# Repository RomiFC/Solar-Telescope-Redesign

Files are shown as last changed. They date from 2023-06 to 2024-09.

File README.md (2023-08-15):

# Solar-Telescope-Redesign

This goal of this project is to redesign and modernize a solar telescope initially created some time before 2013. The telescope receives RF energy from the sun through an x-band feed horn antenna, amplifies and rectifies the signal, then outputs the signal to a voltmeter. More information is available under the [official documentation](/Report/002.35.25.05.20-002-REP-SolarTeleRedesign.pdf).

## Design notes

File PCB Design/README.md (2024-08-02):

# Changelog

## Revision B - 7/24/2024

### Added

- Board characteristics to assembly drawing.
- Board dimensioning to assembly drawing.
- Test points at different stages of amplification.
- Layer indicator to top left of assembly drawing.
- L7912C Negative LDO (Will require additional power supply).
- Summing amplifier stage which will subtract a voltage from the output of the ADL5902-EVALZ in attempt to bring the noise floor closer to 0VDC

### Changed

- Stackup changed from 2-layer, 30 mil RO4350b to 2-layer OSHPark specifications.
- Removed SMA connectors that allowed the stages of the PCB to be used independently as that functionality was not significant.
- Removed ADL5902 Power Detector IC and replaced with a footprint to mount the ADL5902-EVALZ directly on top. Oscillations were detected and further testing is not possible within the current time frame.
- L78XX TO-220 replaced with D2PAK.

### Fixed

- Removed front and back mask from linear regulator pads to improve thermal conductance.
- 15V silkscreen text now correctly reads 12V
- Board dimensions and mounting hole patterns are rounded to clean values (5.05" x 1.8").

## Revision A - 6/29/2023

### First revision 🎉🎉🎉

- This directory contains KiCad files for the PCB. The PCB contains a 15V/5V 1A power supply, an ADL5902 power detector, and a dual LM358 non-inverting amplifier. It was designed to allow users to utilize the individual stages on projects outside of this application.

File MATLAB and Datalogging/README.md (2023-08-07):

# Datalogging

Traces and s2p measurements of components on both the old and new designs, along with spectrum analyzer traces of the telescope in various conditions.

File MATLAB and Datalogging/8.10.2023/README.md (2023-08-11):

# Datalogging

Trace A, B, and C, correspond to the telescope pointing at the Sun, sky, and ground, respectively. FileName_1 uses two ZX60-06203ALN+ LNAs and the 7.8-8.8 GHz filter. FileName_2 uses the same LNAs and a different 8-12 GHz filter. The latter trace may be unusable because the spectrum analyzer had an internal filter-shaped artifact at around 9-13 GHz.

RBW = 300 kHz
VBW = 100 kHz
RMS/Avg Detection
Trace Measurement: Average

## Channel power measurements in dBm/Hz

FileName_1; Center 8.4 GHz, width 900 MHz

- GND = -134.2
- SKY = -136.9
- SUN = -136.3

FileName_2; Center 11 GHz, width 3.8 MHz

- GND = -135.5
- SKY = -136.6
- SUN = -136.2

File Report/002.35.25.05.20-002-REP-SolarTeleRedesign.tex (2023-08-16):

\documentclass[titlepage]{article}

% Suppresses chktex warnings 
% chktex-file 1
% chktex-file 3
% chktex-file 8
% chktex-file 10
% chktex-file 17
% chktex-file 24
% chktex-file 26
% chktex-file 36
% chktex-file 44
% chktex-file 46

\usepackage{geometry}
\usepackage{tikz}
\usepackage{pgfplots}
\usepgfplotslibrary{fillbetween}
\pgfplotsset{compat=1.18}
\pgfplotsset{hide xscale/.style={/pgfplots/xtick scale label code/.code={}}}
\pgfplotsset{hide yscale/.style={/pgfplots/ytick scale label code/.code={}}}
\usepackage{amsmath}
\usepackage{url}
\hyphenation{}	        % Correct bad hyphenation
\usepackage{graphicx}   % For including figures and pictures
\usepackage{float}      % Used to fix location of images i.e.\begin{figure}[H]
\usepackage{fancyhdr}   % For headers and footers
\pagestyle{fancy}
\usepackage{lastpage}   % Allows referencing last page (for footer)
\usepackage{titling}    % To reference title, author, and date
\usepackage{array}      % For fixed-width tables
\usepackage{makecell}   % Formats individual table cells
\usepackage{multirow}   % For multi-row columns (Top left justify header)
\usepackage[american]{circuitikz} % Used to draw circuit and block diagrams
\usepackage{appendix}   
\usepackage{colortbl}   % For coloring table cells
\definecolor{nraoblue}{rgb}{0.776,0.851,0.945}  % Color of table headers
\usepackage{enumitem}   % For formatting enumerated lists
\usepackage[parfill]{parskip}               % Removes paragraph indentation, adds line break
\usepackage[hang, flushmargin]{footmisc}    % Removes footnote indentation
\setenumerate[1]{label={(\arabic*)}}
\usepackage[backend=biber,style=numeric,sorting=none]{biblatex}
\addbibresource{references.bib}
\usepackage{hyperref}   % Allows hyperlinks
\hypersetup{
  colorlinks   = true,  % Colors links instead of ugly boxes
  filecolor    = blue,  % Color for local hyperlinks
  linkcolor    = ., % Color for internal hyperlinks
  citecolor    = ., % Color for citations
  urlcolor     = blue,  % Color for linked urls
}
\usepackage{caption}    % Changes figure/table caption color and size
\definecolor{captioncolor}{RGB}{79,129,189}
\captionsetup{font={
    small, 
    color=captioncolor,
    bf,
}}

% Changes font from Computer Modern to Gill Sans MT
% This requires XeLaTeX or LuaTeX to function
% Add "latex-workshop.latex.recipe.default": "latexmk (xelatex)" to workspace.json
\usepackage{fontspec}
\setmainfont{gil.ttf}[
    BoldFont        = gil-b.ttf,
    ItalicFont      = gil-i.ttf,
    BoldItalicFont  = gil-bi.ttf,
]

% Global TikZ parameters
\tikzset{every picture/.style={/utils/exec={\fontfamily{lmr}}}}
\ctikzset{sources/fill=red!20}
\ctikzset{chips/fill=cyan!20}
\ctikzset{electromechanicals/fill=blue!20}
\ctikzset{blocks/fill=green!20}
\ctikzset{amplifiers/fill=yellow!30}
\tikzset{amp/.append style={fill=yellow!30}}
\tikzset{twoport/.append style={fill=cyan!20}}

% The following lines define a new command \nraocite that cites references in NRAO format RD0X by redefining \cite command to remove brackets. \nraoprecite includes a prenote.
\DeclareCiteCommand{\cite} [\mkbibemph{\emph{}}]
  {\usebibmacro{prenote}}
  {\usebibmacro{citeindex}%
   \printtext[bibhyperref]{\usebibmacro{cite}}}
  {\multicitedelim}
  {\usebibmacro{postnote}}
\DeclareCiteCommand*{\cite} [\mkbibemph\emph{}]
  {\usebibmacro{prenote}}
  {\usebibmacro{citeindex}
   \printtext[bibhyperref]{\usebibmacro{citeyear}}}
  {\multicitedelim}
  {\usebibmacro{postnote}}
\newcommand{\nraocite}[1]{[RD0\cite{#1}]}
\newcommand{\nraoprecite}[2][]{[RD0\cite{#2}{, #1}]}

% This command creates a link to the research directory in filehost
% Nevermind this command is broken and idk why
\newcommand{\filehost}{\href{//filehost/evla/techdocs/RFI/coopshare/remynguyen/SolarTelescope-ASWA/Solar-Telescope-Redesign/Research}{Filehost}}

% ASSIGN TITLE, AUTHOR, DATE, DOCUMENT NUMBER, STATUS, HERE
\title{Redesign of the Visitor Center Solar Telescope}
\author{R. Nguyen
    }% <-this % stops a space
\date{Aug 16, 2023}
\def\docnum{002.35.25.05.20-002-REP}
\def\status{RELEASED}

% HEADERS AND FOOTERS
\renewcommand{\headrulewidth}{0pt}
\fancyheadoffset[L,R]{2cm}
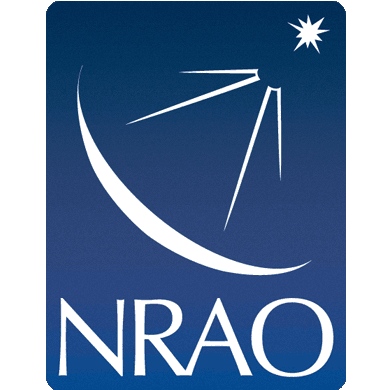
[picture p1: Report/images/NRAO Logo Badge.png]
\fancyhead[L]{\vspace{-1cm}}
\fancyhead[R]{
\renewcommand{\arraystretch}{1.4}
\renewcommand{\arrayrulewidth}{0.25pt}
\begin{tabular}{|w{l}{6.7cm}|w{l}{4.9cm}|w{l}{3.4cm}|}
    \hline
        \multirow[t]{2}{6.7cm}{\textit{\textbf{Title:}} \thetitle} &
        \textit{\textbf{Owner:}} \theauthor &
        \textit{\textbf{Date:}}  \thedate \\
            &   &   \\
    \hline
        \multicolumn{2}{|l|}{
            \textit{\textbf{NRAO Doc \#:}} \docnum  
        } &
        \textit{\textbf{Version:}} A \\
    \hline
\end{tabular}
}
\fancyfoot[C]{Page \textbf{\thepage} of \textbf{\pageref{LastPage}}}

 % DOCUMENT STARTS HERE
\begin{document}
\setlength{\leftmargin}{1in}        % Sets margin
\setlength{\rightmargin}{1in}       % Sets margin
\setlength{\voffset}{-1.2in}        % Moves header up
\setlength{\headheight}{3.5cm}      % Defines header height
\setlength{\textheight}{591pt}      % Extends text/body size down
\setlength{\footskip}{60pt}         % Defines gap between body and footer

\thispagestyle{fancy}
\begin{center}
      \\
     \vspace*{0.5cm}
     \textbf{\huge\thetitle} \\
     \vspace*{0.5cm}
     \large\docnum \\
     \Large Status: \status \\
     \vspace*{0.6cm} \large
     % FIRST TABLE HERE
     \begin{tabular}{|m{6.93cm}|m{4.5cm}|m{2cm}|} \hline
        \rowcolor{nraoblue}
        \textbf{Prepared By} & \textbf{Organization} & \textbf{Date} \\ \hline
        \makecell[l]{Remy Nguyen\\Engineering Intern} & NRAO Electronics Div. & 8/16/2023 \\ 
        \hline
    \end{tabular} \\
    \vspace*{0.8cm}
    \begin{tabular}{|m{3cm}|m{3.5cm}|m{6.93cm}|} \hline
        \rowcolor{nraoblue}
        \textbf{Approvals} & \textbf{Organization} & \textbf{Signatures} \\ \hline
    \end{tabular}
    \renewcommand{\arraystretch}{2}
    % CONTENT OF SECOND TABLE HERE
    \begin{tabular}{|w{l}{3cm}|m{3.5cm}|m{6.93cm}|} \hline
        \parbox{3cm}{\raggedright
        Tyler Mobraten Electronics Engineer II
        } & NRAO Electronics Division \raggedright &  \\ 
        \hline
        \parbox{3cm}{\raggedright
        Steve Wimbrow Electronics Engineer IV
        } & NRAO Electronics Division \raggedright &  \\ 
        \hline
        \parbox{3cm}{\raggedright
        Dave Schafer Division Head
        } & NRAO Electronics Division \raggedright &  \\ 
        \hline
    \end{tabular} \\
    \renewcommand{\arraystretch}{1}
    \vspace*{0.8cm}
    \begin{tabular}{|m{3cm}|m{3.5cm}|m{6.93cm}|} \hline
        \rowcolor{nraoblue}
        \textbf{Released By} & \textbf{Organization} & \textbf{Signature} \\ \hline
    \end{tabular}
    \renewcommand{\arraystretch}{1.5}
    % CONTENT OF THIRD TABLE HERE
    \begin{tabular}{|m{3cm}|m{3.5cm}|m{6.93cm}|} \hline
        \parbox{3cm}{\raggedright
        Dave Schafer Division Head
        } & NRAO Electronics Division \raggedright &  \\ 
        \hline
    \end{tabular}
    \renewcommand{\arraystretch}{1}
\end{center}

% CHANGE RECORD
\newpage
\section*{Change Record}
\begin{center}
\renewcommand{\arraystretch}{1.2}
    \begin{tabular}{|m{1.5cm}|m{2.2cm}|m{2.5cm}|m{1.7cm}|m{5cm}|} \hline
        \rowcolor{nraoblue}
        Version & Date & Author & Affected\newline Section(s) & Reason\\ \hline
    \end{tabular}
\renewcommand{\arraystretch}{1.6}
    \begin{tabular}{|m{1.5cm}|m{2.2cm}|m{2.5cm}|m{1.7cm}|m{5cm}|} \hline
        01 & Aug 15, 2023 & R. Nguyen & All & Initial Draft \\ \hline
        02 & Aug 16, 2023 & \makecell[l]{T. Anderson\\R. Nguyen} & All & Edits \\ \hline
        A  & Aug 16, 2023 & T. Anderson & All & Review \\ \hline
          &          &           &     &               \\ \hline
          &          &           &     &               \\ \hline
          &          &           &     &               \\ \hline
          &          &           &     &               \\ \hline
    \end{tabular}
\renewcommand{\arraystretch}{1}
\end{center}

\newpage
\tableofcontents
\listoffigures
\thispagestyle{fancy}
\newpage

\section{Introduction}

\subsection{Purpose}
Located behind the Visitor Center at the Very Large Array (VLA) is a radio telescope that converts RF solar energy into a DC voltage through amplification. It was originally constructed in 2013 and is no longer functioning as of June 2023. Weathered components and lack of sufficient documentation to repair the telescope to its original state has warranted a redesign of the entire system to be more appealing to visitors and resistant to wear.

\subsection{Scope}
This document will describe the design choices made in development of the new solar telescope. Calculations and experiments to support design decisions will be demonstrated along with constraints and requirements.

\subsection{Verb Convention}
“Must” for an obligation; “must not” for a prohibition. 

“May” for a discretionary action; “should” for a recommendation. 

“Will” is used to indicate a future happening/action. 

\section{Related Documents and Drawings}
\subsection{Applicable Documents}
The following documents may not be directly referenced herein, but may provide necessary context or supporting material.
\begin{center}
\begin{tabular}{|m{2cm}|m{8cm}|m{3cm}|} \hline
    \rowcolor{nraoblue}
    Ref. No. & Document Title & Rev/Doc. No.\\ \hline
    AD01 & Desiderata for Solar Observing with the EVLA & EVLAM\_70 \\ 
    \hline
    AD02 & EVLA Hardware Modifications in Support of Solar Observing & EVLAM\_72 \\
    \hline
\end{tabular}
\end{center}

\subsection{Reference Documents}
The following documents are referenced within this text:
\begin{center}
\renewcommand{\arraystretch}{1.2}
\begin{tabular}{|m{2cm}|m{8cm}|m{3cm}|} \hline
    \rowcolor{nraoblue}
    Ref. No. & Document Title & Rev/Doc. No.\\ \hline
    RD01 & \citefield{solartemp}{title} & \href{https://ipnpr.jpl.nasa.gov/progress_report/42-175/175E.pdf}{Online} \\ \hline
    RD02 & \citefield{aeh}{title} & DSOC Bookcase \\\hline
    RD03 & \citefield{tora}{title} & Privately Owned \\\hline
    RD04 & \citefield{xbandvla}{title} & \href{https://tmo.jpl.nasa.gov/progress_report/42-92/92O.PDF}{Online} \\\hline
    RD05 & \citefield{sfd1986}{title} & \href{https://www.govinfo.gov/content/pkg/GOVPUB-C13-53a55ea34f3ca8aaacf289a9caa0bee6/pdf/GOVPUB-C13-53a55ea34f3ca8aaacf289a9caa0bee6.pdf}{Online} \\\hline
\end{tabular}
\renewcommand{\arraystretch}{1}
\end{center}

\section{System Overview}
The heart of the telescope is an conical corrugated X-band horn antenna originally used to receive Voyager transmissions at 8.4 GHz; this is to be unchanged in the redesign. Power is supplied through a 15 volt linear DC power supply located inside the visitor center in order to eliminate radio frequency interference (RFI) caused by AC power and switching power supplies.

As the telescope is pointed towards the various objects, RF energy is received by the antenna and amplified. A rectifying circuit converts the RF power into a DC voltage and further amplifies it before outputting to a voltmeter. The DC gain should be adjusted so that as the telescope is pointed directly at the sun, the voltmeter should raise noticeably from its value when pointed at a cold sky\footnote{Cold sky is defined when there are no notable RF emitting objects in the beamwidth. Experimentally, these readings seem to be equivalent to the receiver noise floor.}. When pointed at the ground or an object, the reading will increase to a maximum due reflections and filling of the antenna sidelobes. This is further explained in Section~\ref{sec:pwrplots}.

\subsection{Requirements}
Being a visitor center attraction, the device should be engaging and appealing to visitors. In order to achieve this, a transparent enclosure will show the electronics and the voltmeter driven by solar energy will provide user feedback. The enclosure of the previous design was made of some sort of polycarbonate material which suffered from yellowing in the sun. Additionally, small computer fans with a mesh screen mounted directly to the enclosure were used to decrease operating temperature but allowed dust to accumulate over the years. In essence, the new design goals are as follows:
\begin{enumerate}
    \item Utilizes a transparent enclosure or panel to view electronics, ideally one which will not yellow or fade easily.
    \item Must be dustproof and resilient to accumulation of debris inside the enclosure while still venting heat from electronics.
    \item Electronics must be powered by a fixed DC linear power supply and easily serviceable.
    \item There must be a measurable voltage delta when pointing the telescope at various RF sources.
\end{enumerate}
The first two requirements were fulfilled by Tristen James in designing the enclosure. The following requirements will be discussed in this report.

\subsection{Architecture}
\label{sec:arch}
\begin{figure}[!ht]
    \begin{center}
        \begin{circuitikz}
            \draw(0, 0)
            node[
                rxantenna, 
                xscale=-1,
                label = {[xshift=-1.4cm, yshift=-0.5cm]X-band feed}
                ]{}
            to[amp = RF Gain Block, boxed] ++ (2, 0)
            to[bandpass = Filter] ++ (2,0)
            to[detector = Rectifier] ++ (2,0)
            to[amp = DC Gain Block, boxed] ++ (3,0)
            to[qvprobe = Voltmeter] ++ (2,0)
            -| ++ (0.5,-1) node[ground]{};
        \end{circuitikz}
    \caption{RF Signal Block Diagram.}\label{fig:rfblock}
    \end{center}
\end{figure}
Many of the RF components were either reused from the previous design or gathered at no cost. The RF gain block shown in Fig.~\ref{fig:rfblock} and~\ref{fig:rfgain} utilizes 3 low noise amplifiers (LNAs) and an attenuator. The first 2 LNAs are Mini-Circuits ZX60-06203ALN+ which provide a combined gain of 41 dB;\ they are followed by a ZX60-83LN-S+ which provides a mean gain of 15 dB in the filter bandwidth. These amplifiers are followed by an attenuator whose purpose will be described in Section~\ref{sec:tuning}. It is important to note that the receiver noise figure is about 2 dB -- a higher noise figure could result in an undetectable sun/sky delta.
\begin{figure}[!ht]
    \begin{center}
        \begin{circuitikz}
            \draw(0, 0)
            to[short, o-] ++ (0.5,0)
            to[amp, name=a1] ++ (2, 0)
            to[amp, name=a2] ++ (2, 0)
            to[amp, name=a3] ++ (2, 0)
            to[twoport, name=tp, fill=green!20] ++ (2, 0)
            to[short, -o] ++ (0.5,0);
            \draw (tp.center)
            node[resistorshape, anchor = center, rotate = 90, scale = 0.8]{};
            \draw (tp.center)
            ++ (0, 0.6)
            node[anchor = south]{-7 dB};
            \draw (a1.center) ++ (0, 0.6)
            node[anchor=south]{20.5 dB};
            \draw (a2.center) ++ (0, 0.6)
            node[anchor=south]{20.5 dB};
            \draw (a3.center) ++ (0, 0.6)
            node[anchor=south]{15 dB};
        \end{circuitikz}
    \caption{49 dB RF Gain Block.}\label{fig:rfgain}
    \end{center}
\end{figure}

The bandpass filter does not have an attached datasheet but it resembles an equiripple filter and measured a 3 dB passband of about 7.8--8.9 GHz.

The rectifier and DC gain block are integrated into a PCB with SMA connectors. The former utilizes an Analog Devices ADL5902, providing a linear-in-decibel output that can be scaled by the choice of resistors on the board or the following gain element. The DC gain block utilizes an LM358 op amp with adjustable gain via potentiometer.

\subsection{Power Distribution}
\begin{figure}[!ht]
\begin{center}
\begin{circuitikz}
\ctikzloadstyle{legacy}
\ctikzset{bipoles/twoport/width=1}
\tikzset{twoport/.append style={fill=red!20}}
    \draw(0,0)[color=black]
    to[vsource, l_ = $V_{in}$, a^ = 15V] ++ (0,-3)
    node[tlground]{}
    (0, 0) -- ++ (1,0)
    % U1
    to[twoport, t=L7812, name=u1, l=U1] ++ (1.5,0)
    -- ++ (1,0) coordinate (12v)
    -- ++ (2,0)
    % U2
    to[twoport, t=L7805, name=u2, l=U2] ++ (1.5,0)
    -- ++ (1,0) coordinate (5v1)
    -- ++ (2,0) coordinate (5v2)
    -- ++ (2,0) coordinate (5v3)
    to[short, -o] ++ (1,0);
    % Amplifiers
    \draw(5v1.south)
    to[short, f = 150 mA] ++ (0,-2)
    node[plain mono amp, anchor=up, scale = 0.75, name = lna2]{LNA};
    \draw(5v2.south)
    to[short, f = 150 mA] ++ (0,-2)
    node[plain mono amp, anchor=up, scale = 0.75, name = lna3]{LNA};
    \draw(5v3.south)
    to[short, f = 94 mA] ++ (0,-2)
    node[plain mono amp, anchor=up, scale = 0.75, name = lna4]{LNA};
    \draw(lna2.in) to[open, o-o] (lna4.out);
    \draw (lna2.out) -- (lna3.in);
    \draw (lna3.out) -- (lna4.in);
    % ADL5902
    \draw(5v1.north)
    -- ++ (0, 0.2)
    to[short, f_ = 90 mA] ++ (0,1.75)
    node[qfpchip, anchor = pin 3, hide numbers, external pins width = 0, label = {[scale = 0.8]ADL5902}, name = U3]{}
    (U3.north) node[anchor = south]{U3};
    % Fan
    \draw(12v.south)
    to[short, f = 182 mA] ++ (0,-1.75)
    node[elmech, anchor = top, name = fan1]{M}
    (fan1.bottom) node[anchor=north]{Fan};
    \draw(12v.north)
    -- ++ (0, 0.3)
    to[short, f_ = 182 mA] ++ (0,1.75)
    node[elmech, anchor = bottom, name = fan2]{M}
    (fan2.top) node[anchor=south]{Fan};
    % Voltage Labels
    \draw (12v.north east)
    node[anchor = south west]{\color{red}12 V};
    \draw (5v2.north)
    node[anchor = south]{\color{red}5 V};
\end{circuitikz}
\caption{DC Power Distribution Block Diagram (Maximum Ratings).}\label{fig:dcblock}
\end{center}
\end{figure}
As part of the effort to make the telescope more modern and visually appealing, the protoboard on the previous design was replaced with a PCB that contains the voltage regulators, the RF power detector IC, and dual noninverting op amps. The 15 volt supply is dropped to 12 volts and 5 volts via linear regulators, each of which powers different components. Figure~\ref{fig:dcblock} shows the maximum current draw of each component to ensure that the system does not exceed the 1.5 amp rating of the L78XX chips.

\section{Tuning System Gain}
\label{sec:tuning}
Figure~\ref{fig:vpcurve} shows the voltage-power curve of the ADL5902-EVALZ\footnote{Resistor values were changed on the evaluation board to achieve 86.3 mV/dB slope: R6 = 1180$\Omega$ and R2 = 2000$\Omega$} at the telescope's operating frequency. Pointing the telescope at a high temperature object will produce an input power higher than pointing it at the cold sky; this dynamic range is represented by the dotted lines and filled section of the curve\footnote{The range has been enlarged for the purpose of demonstration. The true range is much smaller (Section~\ref{sec:pwrplots})}. Adding attenuation or RF gain will shift this area to the left or right respectively. Adding DC gain will increase the slope of this curve and vice versa.
\begin{figure}[!ht]
\begin{center}
    \begin{tikzpicture}
        \begin{axis}[
            title=$V_{out}$ vs. $P_{in}$ at 8.4 GHz,
            xlabel={$P_{in}$ (dBm)},
            ylabel={$V_{out}$ (V)},
            grid=major,
            xmin=-60, xmax=0,
            ymin=0, ymax=3,
            xtick={-60,-50,...,0},
            ytick={0,0.5,...,3},
            legend style = {
                align = left,
                cells = {anchor=east},
                legend pos=outer north east,
                }
                ]
                \path[name path=xaxis] (axis cs:-60,0) -- (axis cs:0,0);
                \addplot[smooth, blue, name path=f] table [x=Pin,y=Vout] {data/Vout vs Pin.txt};

                \addplot[opacity=0.2, green] fill between [of=f and xaxis, soft clip={domain=-47.5:-37.5}];
                \draw[dashed] (axis cs:-47.5,0) -- (-47.5, 1.25);
                \draw[dashed] (axis cs:-37.5,0) -- (-37.5, 1.25);
                \draw (axis cs:-42.5,1.25)
                node[anchor=south]{Ideal Range};

                \addplot[opacity=0.2, red] fill between [of=f and xaxis, soft clip={domain=-25:-15}];
                \draw[dashed] (axis cs:-25,0) -- (-25, 2.25);
                \draw[dashed] (axis cs:-15,0) -- (-15, 2.25);
                \draw (axis cs:-20,2.25)
                node[anchor=south]{Incorrect Range};
            \end{axis}
\end{tikzpicture}
\caption{Output Voltage of the ADL5902-EVALZ as a Function of Input Power.}
\label{fig:vpcurve}
\end{center}
\end{figure}
Ideally, the RF gain should be adjusted such that the low end is roughly 0 volts whereas the the high end is scaled to 3 volts by the DC gain block. In this case, amplification from the DC gain block will have negligible effect on the low end. If, for some reason, granular attenuation is not possible, the DC gain will cause the nonzero low end to increase above 0 volts. A simple solution is presented in Fig.~\ref{fig:scalingcircuit} where the negative terminal of the voltmeter can be set to reference a nonzero voltage.
\begin{figure}[!ht]
    \begin{center}
        \begin{circuitikz}
            \draw(0, 0)
            node[ampshape, anchor=east, boxed, fill=yellow!30](amp){}
            -- ++ (1, 0)
            to[qvprobe = Voltmeter] ++ (2.5,0)
            -- ++ (1,0) 
            coordinate (p1)
            to[R, l=R2] ++ (3,0)
            -| ++ (0, -0.5)
            node[cground]{};

            \draw(p1)
            to[R, l_=R1] ++ (0, 2)
            node[vcc]{15V};
            \draw[
                line width = 3pt,
                line cap = round,
                dash pattern = on 0pt off 3.5\pgflinewidth,
                ] (amp.west)
               ++ (-8pt, 0)
            -- ++ (-1, 0);
            \draw(amp.north)
            node[anchor=south]{DC Gain Block};
        \end{circuitikz}
    \caption{Optional Output Scaling Circuit.}\label{fig:scalingcircuit}
    \end{center}
\end{figure}
In reality, the sensitivity of the receiver will prevent a perfect 0 to 3 volt scaling at all times. Thus, in order to ensure some amount of voltmeter deflection occurs despite environmental changes, a practical range around 0.5--2.5 volts may be desired.

\subsection{Installation Notes}
Figure~\ref{fig:rfgain} shows 49 dB of RF gain; this was determined to be functional with the antenna and log-detector via testing, however, $\pm$1 dB of attenuation may work if the DC gain block is scaled correctly. Exact numbers are not shown for DC gain because slight variations in cable loss and component accuracy make it difficult to calculate. The easiest way to determine DC gain is simply to measure the voltage readings at the receiver output and adjust accordingly.

\section{Calculating Receiver Input Power}
The first step to determine RF gain will be to find the power delta as the antenna is pointed at the sun from a cold sky; note that this may vary daily and annually depending on solar cycle\nraoprecite[Fig.~2]{solartemp}. This calculation also assumes that solar flux density is constant across the entire frequency range of the receiver. This is a limitation of available information on solar flux density; in practice, it generally increases with frequency\nraocite{sfd1986}. Instantaneous channel power received by the antenna from a celestial source in watts, in an additive white Gaussian noise (AWGN) channel, $P_R$, is defined by Eq.~\ref{eq:power}\nraoprecite[eq.~(41-2)]{aeh}
\begin{align} \label{eq:power}
    P_{R} &= P_{sun} + P_{noise} \\
    P_{R} &= S A_e \Delta f + k_B T \Delta f \nonumber
\end{align}
\begin{align*}
    \text{where:}~S ~&\text{is the source flux density in W m$^{-2}$ Hz$^{-1}$,}\\
    A_e             ~&\text{is the effective aperture area in m$^2$}\\
    \Delta f        ~&\text{is the receiver bandwidth in Hz,}\\
    k_B             ~&\text{is the Boltzmann constant in J K$^{-1}$, and}\\
    T               ~&\text{is the system noise temperature in K.}
\end{align*}
To simplify calculations, we will focus on power spectral density (PSD) defined as $P(f)$ in W/Hz, ignoring the receiver bandwidth for now. Additionally, it is safe to assume that $P_R = P_{noise}$ when the antenna is pointed at a cold sky.
\begin{align} \label{eq:psd}
    P_{R}(f) &= P_{sun}(f) + P_{noise}(f) \\
             &= S A_e + k_B T \nonumber
\end{align}
Effective aperture at a fixed wavelength $\lambda$ can be calculated using measurements of the antenna as shown in Eq.~\ref{eq:ae}\nraoprecite[pg.~(15-27)]{aeh}\nraoprecite[eq.~(5.58)]{tora}
\begin{align} \label{eq:ae}
    A_e &= \frac{\lambda^2}{4\pi}G \\
    &= \frac{\pi d^2}{4} \eta_a \nonumber
\end{align}
\begin{align*} 
    \text{where:}~G ~&\text{is linear antenna gain,}\\
           d        ~&\text{is the diameter of the circular horn at the aperture, and}\\
           \eta_a   ~&\text{is the unitless aperture efficiency.}
\end{align*}
An ideal horn antenna has an $\eta_a$ of 0.522. The calculations for this design will use an approximate value of 0.5\footnote{The x-band horn measured an estimated aperture efficiency of 0.62$\pm$0.03 but only when mounted to the VLA dish\nraocite{xbandvla}. This design will assume the antenna to be a standard horn antenna.}. The antenna diameter at the opening measures 34 cm, resulting in an effective area of 0.0454 m$^2$ or -13.4 dB m$^2$.

Values for solar flux density $S$ must be found within the operating frequency. Ho \textit{et al.}\nraocite{solartemp} measured mean, minimum, and maximum values for solar flux density at 2800 MHz and 8800 MHz but only numbers for the former are shown in the text. However, they claim that solar flux density at 8800 MHz are higher by a factor of 2.17 on average, thus, the mean, minimum, and maximum values at 2800 MHz can be multiplied by 2.17 to achieve approximate values for $S$. Additionally, solar brightness temperature shown in~\nraoprecite[Fig.~5]{solartemp} can be used to calculate solar flux density via~\nraoprecite[eq.~(2)]{solartemp}. The former method shows higher dynamic range and is shown in Table~\ref{tab:sfd} in solar flux units\footnote{One solar flux unit (SFU) is equal to $10^{-22}$ W m$^{-2}$ Hz$^{-1}$.}.
\begin{table}[!ht]
\centering
\begin{tabular}{c|c|c|c}
    & $S_{\min}$ & $S_{\mu}$ & $S_{\max}$ \\ \hline
    2.8 GHz & 70 SFU & 150 SFU & 280 SFU \\
    8.8 GHz & 152 SFU & 326 SFU & 608 SFU
\end{tabular}
\caption{Solar Flux Density $S$ at 8.8 GHz Extrapolated by Multiplying $S$ in~\color{captioncolor}\nraocite{solartemp} at 2.8 GHz by a Factor of 2.17.} \label{tab:sfd}
\end{table}

With values for $S$ and $A_e$ found, we can now calculate $P_{sun}(f)$ with equation~\ref{eq:psd} to be -181.6 dBm/Hz at $S_{\min}$. A problem arises when comparing this to the thermal noise PSD of -174 dBm/Hz at 300 K;\ because the power received by the sun is below the noise floor, the increase in $P_R$ due to $P_{sun}$ will be very small compared to $P_{noise}$.

The nominal 7.6 dB difference between the $P_{noise}(f)$ and $P_{sun}(f)$ means that pointing the antenna at the sun will raise the antenna output power by a mere 0.7 dB at minimum. If a receiver noise figure of 2 dB is to be assumed, this output power delta $\Delta P$ decreases to 0.45 dB\footnote{$\Delta$ is typically used to denote a difference of linear terms. Here it is being used to denote a difference in logarithmic terms which translates to a linear ratio.}.
\begin{align*}
    \Delta P &= \left[ \frac{P_{R}(f)}{P_{noise}(f)} \right] _{dB}\\
             &= \left[ \frac{P_{sun}(f)+P_{noise}(f)}{P_{noise}(f)} \right] _{dB}\\
             &= 10 \log_{10} \left( 1 + 10^{-0.76 - 0.2} \right)\\
             &= 0.452 \text{ dB}
\end{align*}

\subsection{Antenna Power Measurements}
\label{sec:pwrplots}
In order to confirm these calculations, the antenna was connected to an Anritsu MS2720T/720 spectrum analyzer and pointed at various targets.
\begin{figure}[H]
\begin {center}
\begin{tikzpicture}
    \begin{axis}[
        title={Spectrum Analyzer Plot},
        xlabel=Frequency (MHz),
        ylabel={Power (dBm/300kHz)},
        grid=major,
        xmin=7400, xmax=9400,
        ymin=-87, ymax=-78,
        xtick={7400, 7800, ..., 9400},
        ytick={-86, -84, ..., -78},
        legend style = {
            align = left,
            cells = {anchor=west},
            legend pos=outer north east,
            }
            ]
        \addplot[orange!70] table [x index = 5, y index = 4] {data/FileName_1.txt};
        \addplot[blue!70] table [x index = 1, y index = 0] {data/FileName_1.txt};
        \addplot[red!80] table [x index = 3, y index = 2] {data/FileName_1.txt};
        \legend{Ground\\(-134.2 dBm/Hz), Sun\\(-136.3 dBm/Hz), Cold Sky\\(-136.9 dBm/Hz)}
    \end{axis}
\end{tikzpicture}
\caption{Signal Trace With 41 dB of Gain From Two ZX60-06203ALN+ LNAs.}\label{fig:specan1}
\end {center}
\end{figure}
Mean channel power measurements on the Anritsu from 7.95 to 8.85 GHz show a 2.7 dB ground/sky delta and a 0.6 dB sun/sky delta. It is difficult to calculate the RF power received from the ground prior to measurement, however, the sun/sky delta is well within range of expected values.

\subsection{Final Thoughts}
These measurements and the preceding calculations were the basis for design decisions in Section~\ref{sec:arch}. It's possible other architectures would operate more favorably but further testing is required. Some ideas to increase sun/sky dynamic range would be to sum the two polarized feeds from the antenna via combiner or to create dual-channel rectifier and combine the outputs via summing op-amp, however, these remain as hypotheses at the time.

\end{document}

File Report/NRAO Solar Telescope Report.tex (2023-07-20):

\documentclass[titlepage]{article}
\setlength{\headheight}{23pt}
\addtolength{\topmargin}{-11pt}

\usepackage{geometry}
\usepackage{tikz}
\usepackage{pgfplots}
\pgfplotsset{compat=1.18}
\pgfplotsset{hide xscale/.style={/pgfplots/xtick scale label code/.code={}}}
\pgfplotsset{hide yscale/.style={/pgfplots/ytick scale label code/.code={}}}
\usepackage{amsmath}
\usepackage{url}
\hyphenation{op-tical net-works semi-conduc-tor}	% Correct bad hyphenation
\usepackage{graphicx}   % For including figures and pictures
\usepackage{float}      % Used to fix location of images i.e.\begin{figure}[H]
\usepackage{fancyhdr}   % For headers and footers
\pagestyle{fancy}
\usepackage{titling}    % To reference title, author, and date
\usepackage{array}      % For fixed-width tables
\usepackage[american]{circuitikz} % Used to draw circuit and block diagrams
\usepackage{appendix}   
\usepackage{colortbl}   % For coloring table cells
\usepackage{enumitem}   % For formatting enumerated lists
\setenumerate[1]{label={(\arabic*)}}
\usepackage[backend=biber,style=numeric,sorting=none]{biblatex}
\addbibresource{references.bib}

% Global CircuiTikZ parameters
\ctikzset{sources/fill=red!20}
\ctikzset{chips/fill=cyan!20}
\ctikzset{electromechanicals/fill=blue!20}
\ctikzset{blocks/fill=green!20}
\ctikzset{amplifiers/fill=yellow!30}
\tikzset{amp/.append style={fill=yellow!30}}
\tikzset{twoport/.append style={fill=cyan!20}}

% The following lines define a new command \nraocite that cites references in NRAO format RD0X by redefining \cite command to remove brackets. \nraoprecite includes a prenote.
\DeclareCiteCommand{\cite}[\mkbibemph{\emph{}}]
  {\usebibmacro{prenote}}
  {\usebibmacro{citeindex}%
   \printtext[bibhyperref]{\usebibmacro{cite}}}
  {\multicitedelim}
  {\usebibmacro{postnote}}
\DeclareCiteCommand*{\cite}[\mkbibemph\emph{}]
  {\usebibmacro{prenote}}
  {\usebibmacro{citeindex}
   \printtext[bibhyperref]{\usebibmacro{citeyear}}}
  {\multicitedelim}
  {\usebibmacro{postnote}}
\newcommand{\nraocite}[1]{[RD0\cite{#1}]}
\newcommand{\nraoprecite}[2][]{[RD0\cite{#2}{, #1}]}

% Suppresses chktex warnings 
% chktex-file 1
% chktex-file 3
% chktex-file 8
% chktex-file 24
% chktex-file 44
% chktex-file 46

% ASSIGN TITLE, AUTHOR, DATE, DOCUMENT NUMBER, STATUS, HERE
\title{Redesign of the Visitor Center Solar Telescope}
\author{Remy Nguyen
    }% <-this % stops a space
\date{June 21, 2023}
\def\docnum{[Assign Here]}
\def\status{\textcolor{red}{Draft}}

% HEADERS AND FOOTERS
% If title is too long, write in text and use \\ to make line breaks
\fancyhead[L]{\textit{\thetitle} \\ \textit{NRAO Doc. \#:} \docnum}
\fancyhead[R]{\textit{\theauthor} \\ \thedate}

 % DOCUMENT STARTS HERE
\begin{document}
\definecolor{nraoblue}{rgb}{0.776,0.851,0.945}  % Color of table headers
\setlength{\leftmargin}{1in}
\setlength{\rightmargin}{1in}

\begin{titlepage}
\begin{center}
      \\
     \vspace*{0.5cm}
     \textbf{\Huge\thetitle} \\
     \vspace*{0.5cm}
     \large\docnum \\
     \huge Status: \status \\
     \vspace*{1cm} \large
     % FIRST TABLE HERE
     \begin{tabular}{|m{6.5cm}|m{5cm}|m{2cm}|} \hline
        \rowcolor{nraoblue}
        \textbf{Prepared By} & \textbf{Organization} & \textbf{Date} \\ \hline
        R. Nguyen & NRAO Electronics Div. & 6/21/2023 \\ 
        \hline
    \end{tabular} \\
    \vspace*{1cm}
    \begin{tabular}{|m{3cm}|m{3.5cm}|m{7cm}|} \hline
        \rowcolor{nraoblue}
        \textbf{Approvals} & \textbf{Organization} & \textbf{Signatures} \\ \hline
    \end{tabular}
    \renewcommand{\arraystretch}{1.5}
    % CONTENT OF SECOND TABLE HERE
    \begin{tabular}{|m{3cm}|m{3.5cm}|m{7cm}|}
        T. Mobraten & NRAO Electronics Division &  \\ 
        \hline
        S. Wimbrow & NRAO Electronics Division &  \\ 
        \hline
        D. Schafer & NRAO Electronics Division &  \\ 
        \hline
    \end{tabular} \\
    \renewcommand{\arraystretch}{1}
    \vspace*{1cm}
    \begin{tabular}{|m{3cm}|m{3.5cm}|m{7cm}|} \hline
        \rowcolor{nraoblue}
        \textbf{Released By} & \textbf{Organization} & \textbf{Signature} \\ \hline
    \end{tabular}
    \renewcommand{\arraystretch}{2}
    % CONTENT OF THIRD TABLE HERE
    \begin{tabular}{|m{3cm}|m{3.5cm}|m{7cm}|}
        D. Schafer & NRAO Electronics Division &  \\ 
        \hline
    \end{tabular}
    \renewcommand{\arraystretch}{1}
\end{center}
\end{titlepage}

\tableofcontents
\listoffigures
\thispagestyle{fancy}
\newpage

\section{Introduction}

\subsection{Purpose}
Located behind the Visitor Center at the Very Large Array (VLA) is a radio telescope that converts RF solar energy into a DC voltage through amplification. It was originally constructed in 2013 and is no longer functioning as of June 2023. Weathered components and lack of sufficient documentation to repair the telescope to its original state has warranted a redesign of the entire system to be more appealing to visitors and resistant to wear.

\subsection{Scope}
This document will describe the design choices made in development of the new solar telescope. Calculations and experiments to support design decisions will be demonstrated along with constraints and requirements.

\section{Related Documents and Drawings}
\subsection{Applicable Documents}
The following documents may not be directly referenced herein, but may provide necessary context or supporting material.
\begin{center}
\begin{tabular}{|m{2cm}|m{7cm}|m{2.5cm}|} \hline
    \rowcolor{nraoblue}
    Ref. No. & Document Title & Rev/Doc. No.\\ \hline
    AD01 & Desiderata for Solar Observing with the EVLA & EVLAM\_70 \\ 
    \hline
    AD02 & EVLA Hardware Modifications in Support of Solar Observing & EVLAM\_72 \\
    \hline
\end{tabular}
\end{center}

\subsection{Reference Documents}
The following documents are referenced within this text:
\begin{center}
\renewcommand{\arraystretch}{1.2}
\begin{tabular}{|m{2cm}|m{7cm}|m{2.5cm}|} \hline
    \rowcolor{nraoblue}
    Ref. No. & Document Title & Rev/Doc. No.\\ \hline
    RD01 & \citefield{solartemp}{title} & 0001 \\ \hline
    RD02 & \citefield{aeh}{title} & 0002 \\\hline
    RD03 & \citefield{tora}{title} & 0003 \\\hline
    RD04 & \citefield{xbandvla}{title} & 0004 \\\hline
    RD05 & \citefield{sfd1986}{title} & 0005 \\\hline
\end{tabular}
\renewcommand{\arraystretch}{1}
\end{center}

\section{System Overview}
The heart of the telescope is an conical corrugated X-band horn antenna originally used to receive Voyager transmissions at 8.4 GHz; this is to be unchanged in the redesign. Power is supplied through a 15 volt linear DC power supply located inside the visitor center in order to eliminate radio frequency interference (RFI) caused by AC power and switching power supplies.

As the telescope is pointed towards the sun, RF energy is received by the antenna and amplified. A rectifying circuit converts the RF power into a DC voltage and further amplifies it before outputting to a voltmeter. The DC gain should be adjusted so that as the telescope is pointed towards the sun with clear skies, the voltmeter should read a maximum 5 volts; as the telescope is pointed towards the ground or away from the sun, the voltmeter reading should decrease noticeably.

\subsection{Requirements}
Being a visitor center attraction, the device must be engaging and appealing to visitors. In order to achieve this, the device must be at least partially transparent to show visible electronics and have a voltmeter that is driven by solar energy. The enclosure of the previous design was made of some sort of polycarbonate material which suffered from yellowing in the sun. Additionally, small computer fans with a mesh screen mounted directly to the enclosure were used to decrease operating temperature but allowed dust to accumulate over the years. In essence, the new design goals are as follows:
\begin{enumerate}
    \item Utilizes a transparent enclosure or panel to view electronics, ideally one which will not yellow or fade easily.
    \item Must be dustproof and resilient to accumulation of debris inside the enclosure while still venting heat from electronics.
    \item Use readily available parts when possible to keep costs low.
    \item Electronics must be powered by a fixed DC linear power supply and be easily serviceable.
\end{enumerate}

\subsection{Architecture}
\begin{figure}[!ht]
    \begin{center}
        \begin{circuitikz}
            \draw(0, 0)
            node[
                rxantenna, 
                xscale=-1,
                label = {[xshift=-1.4cm, yshift=-0.5cm]X-band feed}
                ]{}
            to[amp = RF Gain Block, boxed] ++ (2, 0)
            to[bandpass = Filter] ++ (2,0)
            to[detector = Rectifier] ++ (2,0)
            to[amp = DC Gain Block, boxed] ++ (3,0)
            to[qvprobe = Voltmeter] ++ (2,0)
            -| ++ (0.5,-1) node[ground]{};
        \end{circuitikz}
    \caption{RF signal block diagram}\label{fig:rfblock}
    \end{center}
\end{figure}
Many of the RF components were either reused from the previous design or gathered at no cost. The RF gain block shown in Fig.~\ref{fig:rfblock} and~\ref{fig:rfgain} utilizes 4 low noise amplifiers (LNAs) and an attenuator to provide better impedance matching. The first 3 LNAs are Mini-Circuits ZX60-83LN-S+ which provide a measured 15dB of gain at 8.4 GHz each; they are followed by a single 6 dB attenuator and an ALS-04-0149 LNA in that order. The ALS-04-0149 does not have a readily available datasheet but measured 27dB of gain at 8.4 GHz.
\begin{figure}[!ht]
    \begin{center}
        \begin{circuitikz}
            \draw(0, 0)
            to[short, o-] ++ (0.5,0)
            to[amp] ++ (2, 0)
            to[amp, l=ZX60-83LN-S+ (x3)] ++ (2, 0)
            to[amp] ++ (2, 0)
            to[twoport, name=tp, fill=green!20] ++ (2, 0)
            to[amp = ALS-04-0149] ++ (2, 0)
            to[short, -o] ++ (0.5,0);
            \draw (tp.center)
            node[resistorshape, anchor = center, rotate = 90, scale = 0.8]{};
            \draw (tp.north)
            node[anchor = south]{-6 dB};
        \end{circuitikz}
    \caption{66 dB RF gain block}\label{fig:rfgain}
    \end{center}
\end{figure}

The bandpass filter does not have an attached datasheet but it resembles an equiripple filter and measured a 3 dB passband of about 7.8--8.9 GHz.

The rectifier and DC gain block are integrated into a PCB with SMA connectors. The former utilizes an Analog Devices ADL5902, providing a linear-in-decibel output that can be scaled by the choice of resistors on the board or the following gain element. The DC gain block utilizes an LM358 op amp with an adjustable gain via potentiometer.

\subsection{Power Distribution}
As part of the effort to make the telescope more modern and visually appealing, the protoboard on the previous design was replaced with a dual layer PCB which contains the voltage regulators, the RF power detector IC, and the dual noninverting op amps. The 15 volt supply is used to bias the ALS-04-0149, 12 volts is used to power the fan and op amps, whereas 5 volts is used to bias the ADL5902 and the ZX60-83LN-S+ LNAs.
\begin{figure}[!ht]
\begin{center}
\ctikzloadstyle{legacy}
\ctikzset{bipoles/twoport/width=1}
\begin{circuitikz}
    \draw(0,0)[color=black]
    to[vsource, l_ = $V_{in}$, a^ = 15V] ++ (0,-3)
    node[tlground]{}
    (0, 0) -- ++ (1,0)
    % U1
    to[twoport, t=L7812, name=u1, l=U1] ++ (1.5,0)
    -- ++ (1,0) node[anchor=south, name=12v]{12 V}
    -- ++ (1,0)
    % U2
    to[twoport, t=L7805, name=u2, l=U2] ++ (1.5,0)
    -- ++ (1,0) node[anchor=south, name=5v1]{}
    -- ++ (2,0) node[anchor=south, name=5v2]{5 V}
    -- ++ (2,0) node[anchor=south, name=5v3]{}
    to[short, -o] ++ (1,0);
    % Amplifiers
    \draw(0,0)
    to[short, f = 150 mA] ++ (0,2)
    node[plain mono amp, anchor=down, scale = 0.75, name = lna1]{LNA};
    \draw(5v1.south)
    to[short, f = 94 mA] ++ (0,-2)
    node[plain mono amp, anchor=up, scale = 0.75, name = lna2]{LNA};
    \draw(5v2.south)
    to[short, f = 94 mA] ++ (0,-2)
    node[plain mono amp, anchor=up, scale = 0.75, name = lna3]{LNA};
    \draw(5v3.south)
    to[short, f = 94 mA] ++ (0,-2)
    node[plain mono amp, anchor=up, scale = 0.75, name = lna4]{LNA};
    \draw(lna1.out) to[open, o-o] (lna2.in);
    \draw(lna2.out) -- (lna3.in);
    \draw(lna3.out) -- (lna4.in);
    \draw(lna1.in) to[short, o-] ++ (0,0);
    \draw(lna4.out) to[short, o-] ++ (0,0);
    % ADL5902
    \draw(5v1.south)
    to[short, f_ = 90 mA] ++ (0,2)
    node[qfpchip, anchor = pin 3, hide numbers, external pins width = 0, label = {[scale = 0.8]ADL5902}, name = U3]{}
    (U3.north) node[anchor = south]{U3};
    % Fan
    \draw(12v.south)
    to[short, f = 182 mA] ++ (0,-1.75)
    node[elmech, anchor = top, name = fan]{M}
    (fan.bottom) node[anchor=north]{Fan};
\end{circuitikz}
\caption{DC power distribution block diagram (Maximum ratings)}\label{fig:dcblock}
\end{center}
\end{figure}
Figure~\ref{fig:dcblock} shows the maximum current draw of each component to ensure that the system does not exceed the 1.5 A rating of the L78XX chips.

\section{Calculating RF Gain}
The rectifier block has a linear region of RF input power to output voltage; the purpose of the gain elements is to shift the signal power into this linear region of operation. At the frequency and temperature of operation, the linear region was chosen to be -30 dBm to 0 dBm based on information available in the datasheet. This is fixed with a 30 dB dynamic range but antenna input power may vary daily and annually depending on solar cycle\nraoprecite[Fig.~2]{solartemp}.

The first step to determine RF gain will be to find the range of antenna input power when pointed at the sun. Instantaneous power received by the antenna from a celestial source in watts, $P_R$, is defined by Eq.~\ref{eq:power}
\begin{equation}
    P_R = S A_e \Delta f
\label{eq:power}
\end{equation}
where $S$ is the source flux density in W m$^{-2}$ Hz$^{-1}$, $A_e$ is the effective aperture area in m$^2$, and $\Delta f$ is the receiver bandwidth in Hz\nraoprecite[eq.~(41-2)]{aeh}. Effective aperture can be calculated using measurements of the antenna as shown in Eq.~\ref{eq:ae}
\begin{equation} \label{eq:ae}
\begin{split}
    A_e &= \frac{\lambda^2}{4\pi}G \\
    &= \frac{\pi d^2}{4} \eta_a
\end{split}
\end{equation}
where $G$ is linear antenna gain, $d$ is the diameter of the circular horn at the aperture, and $\eta_a$ is the unitless aperture efficiency\nraoprecite[pg.~(15-27)]{aeh}\nraoprecite[eq.~(5.58)]{tora}. An ideal horn antenna has an $\eta_a$ of 0.522. The calculations for this design will use an approximate value of 0.5\footnote{The x-band horn measured an estimated aperture efficiency of 0.62$\pm$0.03 but only when mounted to the VLA dish\nraocite{xbandvla}. This design will assume the antenna to be a standard horn antenna.}. The antenna diameter at the opening measured to be 34 cm, resulting in an effective area of 0.0454 m$^2$ or -13.4 dB m$^2$.

Receiver bandwidth $\Delta f$ can be defined by the bandwidth of the bandpass filter in Fig.~\ref{fig:rfblock}, thus, the received power $P_R$ is more representative of channel power without any amplification, rather than antenna output power, as the antenna is a wideband feed with a higher bandwidth than the filter. In this case, receiver bandwidth is defined to be 1100 MHz or 90.4 dB Hz.

Lastly, values for solar flux density $S$ must be found within the operating frequency. Ho \textit{et al.}\nraocite{solartemp} measured mean, minimum, and maximum values for solar flux density at 2800 MHz and 8800 MHz but only numbers for the former are shown in the text. However, they claim that solar flux density at 8800 MHz are higher by a factor of 2.17 on average, thus, the mean, minimum, and maximum values at 2800 MHz can be multiplied by 2.17 to achieve approximate values for $S$. Additionally, solar brightness temperature shown in~\nraoprecite[Fig.~5]{solartemp} can be used to calculate solar flux density via~\nraoprecite[eq.~(2)]{solartemp}. The former method shows higher dynamic range and is shown in Table~\ref{tab:sfd} in solar flux units\footnote{One solar flux unit (SFU) is equal to $10^{-22}$ W m$^{-2}$ Hz$^{-1}$.}.
\begin{table}[!ht]
\centering
\begin{tabular}{c|c|c|c}
    & $S_{\min}$ & $S_{\mu}$ & $S_{\max}$ \\ \hline
    2.8 GHz & 70 SFU & 150 SFU & 280 SFU \\
    8.8 GHz & 152 SFU & 326 SFU & 608 SFU
\end{tabular}
\label{tab:sfd}
\caption{Solar Flux Density $S$ at 8.8 GHz extrapolated by multiplying $S$ in~\nraocite{solartemp} at 2.8 GHz by a factor of 2.17.}
\end{table}

With values for $S$, $A_e$, and $\Delta f$ found, we can now calculate the antenna channel power $P_R$ with equation~\ref{eq:power} to be -87.9 dBm at $S_{\mu}$. Calculating $P_R$ at $S_{\min}$ and $S_{\max}$ show a roughly $\pm$3 dBm variation in $P_R$. Note that this calculation assumes that solar flux density is constant across the entire frequency range of the receiver. This is a limitation of available information on solar flux density; in practice, $S$ generally increases with frequency\nraocite{sfd1986}.

\subsection{Antenna Power Measurements}
In order to confirm these calculations, the antenna was connected to an Anritsu Model MS2720T/720 Spectrum Analyzer centered at 8.4 GHz spanning 100 MHz and pointed towards the sun.
\begin{figure}[H]%[!ht]
\begin {center}
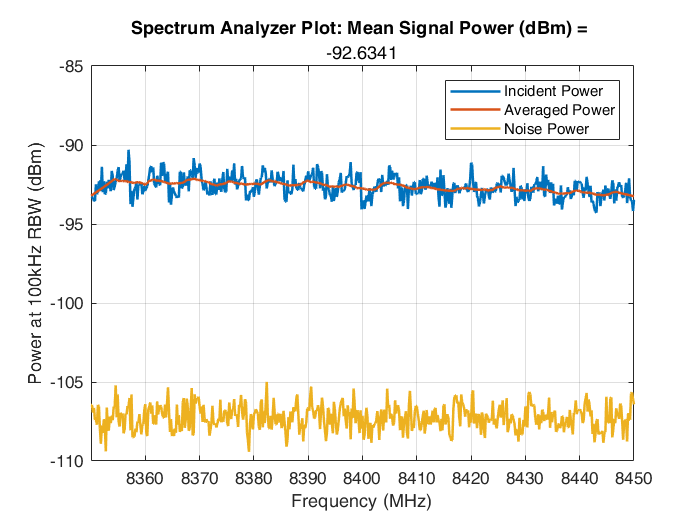
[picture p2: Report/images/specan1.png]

\caption{Signal trace with 30 dB of gain from two ZX60-83LN-S+ LNAs. Resolution bandwidth is 100 kHz.}
\label{fig:specan1}
\end {center}
\end{figure}
The Anritsu is not capable of performing channel power measurements, so, assuming the mean signal power in Fig.~\ref{fig:specan1} can be extrapolated to the entire receiver bandwidth, channel power is calculated as follows:
\begin{align*}
    P_R &= P_{\mu} - G_{dB} - \left(RBW\right)_{dB} + \left(BW\right)_{dB}\\
        &= -92.6\ \text{dBm} - 30 - 50 + 90.4\\
        &= -82.2\ \text{dBm}
\end{align*}
This measurement is about 5 dB greater than calculated but is within the degree of accuracy necessary for this design. It's possible this error was caused by assuming equal power throughout the entire passband, or due to the fact that this operating frequency is outside the bandwidth of the amplifiers used, thus resulting in nonlinear gain across frequency.

The 4 LNAs and single 6dB attenuator chosen provide a combined 66 dB of gain; thus, the ADL5902 incident power would measure approximately -16 dBm when pointed at the sun, well within its operating region.

\appendix
\section{Appendix Title}

\end{document}

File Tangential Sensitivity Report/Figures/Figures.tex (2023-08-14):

\documentclass{report}
\pagestyle{empty}
\usepackage{upgreek}
\usepackage[american]{circuitikz}
\usepackage{pgfplots}
\usepackage[letterpaper]{geometry}
\pgfplotsset{compat=1.18}
\pgfplotsset{hide xscale/.style={/pgfplots/xtick scale label code/.code={}}}
\pgfplotsset{hide yscale/.style={/pgfplots/ytick scale label code/.code={}}}
\usetikzlibrary{shapes.geometric}
\usetikzlibrary{fit}
% chktex-file 1
% chktex-file 8
% chktex-file 36

\begin{document}
\begin{center}

\begin{tikzpicture}
    \begin{axis}[
        title=Example Oscilloscope Output,
        xlabel={Periods},
        ylabel={$V_{out}$ (mV)},
        grid=major,
        xmin=-0.5, xmax=0.5,
        ymin=-0.5, ymax=1.5,
        xtick={-0.5, -0.25, ..., 0.5},
        ytick={0, 0.5, ..., 1.5},
    ]
    \addplot[sharp plot, color=blue] table {Data/exampleTS.txt};
    
    \end{axis}
\end{tikzpicture}

\vspace{1cm}
    
\begin{tikzpicture}
    \begin{axis}[
        title=Receiver Tangential Sensitivity,
        xlabel={Frequency (GHz)},
        ylabel={$P_{in}$ (dBm)},
        grid=major,
        xmin=2, xmax=10,
        ymin=-65, ymax=0,
        xtick={2,...,10},
        ytick={-60,-50,...,-10},
        legend style = {
            align = left,
            cells = {anchor=east},
            legend pos=outer north east,
        }
    ]
    \addplot[smooth, blue!70] table [x index=0,y index=1] {Data/TanSensADL5902.txt};
    \addlegendentry{ADL5902 Only};
    \addplot[smooth, green!50!teal!100] table [x index=0,y index=3] {Data/TanSensADL5902.txt};
    \addlegendentry{RF-DFS Board};
    \addplot[smooth, red!80] table [x index=0,y index=2] {Data/TanSensADL5902.txt};
    \addlegendentry{ZX60-83LN-S+};
    
    \end{axis}
\end{tikzpicture}

\vspace{1cm}

\begin{circuitikz}
    \draw (0,0)
    node[vsourcesinshape, anchor=south, rotate=90](source){}
    -- ++ (0.4,0)
    to[twoport, name=tp] ++ (2.5, 0)
    to[amp, l=Preamp, name=lna] ++ (2, 0)
    -- ++ (1,0)
    node[qfpchip,
    num pins=6,
    anchor=west,
    hide numbers,
    external pins width=0,
    ](adl){}
    (adl.north)
    node[anchor=south, name=adllabel]{ADL5902}
    (adl.east)
    -- ++ (1.5,0)
    node[oscopeshape, anchor=left](scope){};
    % Attenuator
    \draw (tp.center)
    node[vresistorshape, anchor = center, rotate = -90, xscale = -1, scale = 0.8]{};
    % Labels
    \draw (source.east)
    node[anchor=south]{Signal Gen.};
    \draw (scope.north)
    node[anchor=south]{Oscilloscope};

    % Box
    \node[
        rectangle,
        draw,
        dashed, fit= (lna) (lnalabel) (adl) (adllabel),
        inner sep=5,
        color=blue](box){};
    \draw[color=blue] (box.north)
    node[anchor=south]{Receiver};
\end{circuitikz}

\vspace{1cm}

\begin{tikzpicture}
    \begin{axis}[
        title=$V_{out}$ vs. $P_{in}$ at 8.4 GHz,
        xlabel={$P_{in}$ (dBm)},
        ylabel={$V_{out}$ (V)},
        grid=major,
        xmin=-60, xmax=0,
        ymin=0, ymax=3,
        xtick={-60,-50,...,0},
        ytick={0,0.5,...,3},
        legend style = {
            align = left,
            cells = {anchor=east},
            legend pos=outer north east,
        }
    ]
    \addplot[smooth, blue] table [x=Pin,y=Vout] {Data/Vout vs Pin.txt};
    
    \end{axis}
\end{tikzpicture}

\vspace{1cm}

\begin{tikzpicture}
    \begin{axis}[
        scale only axis,
        title=Amplifier Gain and Noise Figure,
        xlabel={Frequency (GHz)},
        ylabel={$S_{21}$ (dB)},
        grid=major,
        axis y line*=left,
        scaled x ticks=base 10:-3,
        hide xscale,
        xmin=0, xmax=10000,
        ymin=0, ymax=50,
        xtick={0,2000,...,10000},
        ytick={10,20,...,50},
    ]
    \addplot[smooth, red!80] table [x index=0,y index=1] {Data/rfdfs-6g-sparam.txt};
    \addlegendentry{ZX60-83LN-S+};
    \addplot[smooth, green!50!teal!100] table [x index=0,y index=1] {Data/Amplifiers and Filter Sparam.txt};
    \addlegendentry{RF-DFS Board};

    \draw (axis cs: 4800,22.5)
    ellipse (200 and 4);
    \draw (axis cs: 4800,26.5)
    [->] -- (4300, 26.5);

    \end{axis}

    \begin{axis}[
        scale only axis,
        ylabel={$NF$ (dB)},
        grid=major,
        axis y line*=right,
        axis x line=none,
        scaled x ticks=base 10:-3,
        hide xscale,
        xmin=0, xmax=10000,
        ymin=0, ymax=5,
        xtick={0,2000,...,10000},
        ytick={1,...,5},
        legend style = {
            align = left,
            cells = {anchor=east},
            legend pos=outer north east,
        }
    ]
    \addplot[smooth, red!80] table [x index=0,y index=1] {Data/nf-zx60-83.txt};
    \addplot[smooth, green!50!teal!100] table [x index=0,y index=1] {Data/nf-pma2-6g.txt};
    \addplot[smooth, blue, loosely dashed] table [x index=0,y index=1] {Data/nf-zx60-83.txt};
    \addplot[smooth, blue, loosely dashed] table [x index=0,y index=1] {Data/nf-pma2-6g.txt};
    
    \draw (axis cs: 2000,1)
    ellipse (200 and 0.6);
    \draw (axis cs: 2000,0.4)
    [->] -- ++ (500, 0);
    
    \end{axis}
\end{tikzpicture}

\vspace{1cm}

\end{center}
\end{document}

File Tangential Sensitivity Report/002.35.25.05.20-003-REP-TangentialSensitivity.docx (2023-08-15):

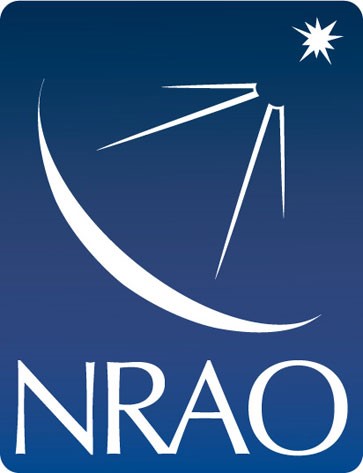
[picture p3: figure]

Tangential Sensitivity of ADL5902-Based Receivers

[002.35.25.05.20-003]

Status: Draft

PREPARED BY | ORGANIZATION | DATE
R. Nguyen | NRAO Electronics Division | 8/15/2023

APPROVALS | ORGANIZATION | SIGNATURES

RELEASED BY | ORGANIZATION | SIGNATURE

Change Record

Version | Date | Author | Affected Section(s) | Reason
1 | 8/15/2023 | R. Nguyen | All | Initial Draft

# 1 Introduction

## Purpose

The ADL5902 is an RF power detector which has a linear-in-decibel output voltage to input power ratio. The following tangential sensitivity measurements will more accurately describe the usability of an ADL5902 based receiver by determining the lowest possible input power that produces a discernable pulse at the output.

## Scope

This report will define tangential sensitivity and outline the experiments performed.

# 2 Related Documents and Drawings

## Applicable Documents

The following documents may not be directly referenced herein, but provide necessary context or supporting material.

Ref. No. | Document Title | Rev/Doc. No.
AD01 | ADL5902 Datasheet | Filehost, Online (https://www.analog.com/media/en/technical-documentation/data-sheets/ADL5902.pdf)
AD02 | PMA2-63LN+ Datasheet | Online (https://www.minicircuits.com/pdfs/PMA2-63LN+.pdf)
AD03 | PMA2-123LN+ Datasheet | Online (https://www.minicircuits.com/pdfs/PMA2-123LN+.pdf)

## Reference Documents

The following documents are referenced within this text:

Ref. No. | Document Title | Rev/Doc. No.
RD01 | The Criterion for the Tangential Sensitivity Measurement | Hewlett Packard AN 956-1 (Filehost), Online (http://www.hp.woodshot.com/hprfhelp/4_downld/lit/diodelit/an956-1.pdf)

# 3 Procedure

Tangential signal sensitivity (TSS) is defined to be the power level of an input pulse to a receiver in which the output shows 8 dB of signal-to-noise ratio (SNR). By reading the output of the receiver on an oscilloscope, 8 dB of SNR can be determined by an RMS voltage ratio of 2.5[RD01]. In some cases, the TSS level is determined subjectively to be the input power level at which the bottom of the output signal waveform touches the top of the noise floor on an oscilloscope, as shown in Fig. 1.

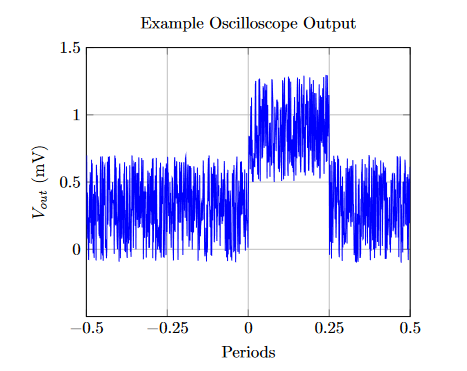
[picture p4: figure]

Figure 1: Receiver output where pulsed signal power sits just above the noise floor.

The setup to this experiment is shown in Fig. 2 and as follows: a signal generator is used to create a pulsed input signal at a given frequency and an oscilloscope is used to read the output of the receiver. Then, a step attenuator is used to tune the output trace to a 2.5:1 ratio of signal-to-noise RMS voltage. As attenuation increases, the RMS voltage of the output pulse decreases and vice versa.

In this case, a 1 kHz pulse with a 20% duty cycle was used; the output of each receiver setup when biased with no input signal measured roughly 400 µV, thus, an RMS signal voltage of 1 mV is desired for TSS.

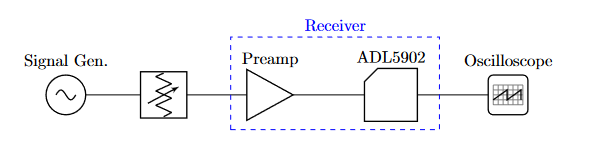
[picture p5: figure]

Figure 2: Test setup block diagram.

# 4 Results

The ADL5902 evaluation board was used in each receiver although it has been slightly modified to increase the gain to approximately 86 mV/dB; R6 was replaced with a 1180Ω resistor and R2 was replaced with a 2kΩ resistor. The voltage-power curve in this configuration is shown in Fig. 3.

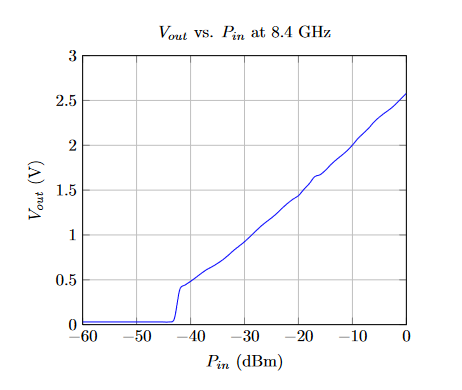
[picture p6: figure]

Figure 3: Power sweep of the ADL5902-EVALZ. R6 = 1180Ω and R2 = 2000Ω.

This V-P curve is a good baseline for systems utilizing the ADL5902 but shows a steep voltage slope immediately after the minimum power limit. Because of this, a more accurate measure of TSS would likely be possible with a precision step attenuator below 1 dB per step. In any case, TSS levels were measured across a frequency range of 2-10 GHz at various receiver configurations. All of these are outlined in Fig. 4.

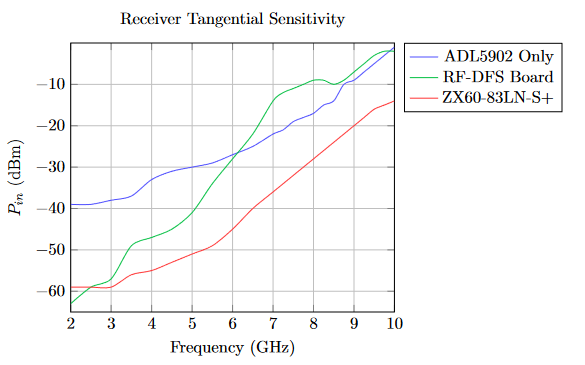
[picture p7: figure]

Figure 4: Tangential sensitivity of the ADL5902 with different preamplifiers.

The RF-DFS board used contains two PMA2-63LN+ amplifiers and a 1 dB attenuator in between. Because the RF-DFS LNAs are built for very low noise, the gain drops significantly after 6 GHz and although noise figure measurements from the datasheet only go up to 6 GHz, it is a fair assumption that noise performance also drops. Note that noise figure numbers were taken from the Mini-Circuits datasheets. The RF-DFS uses two PMA2-63LN+ amplifiers and thus will have a noise figure slightly higher than shown in Fig. 5.

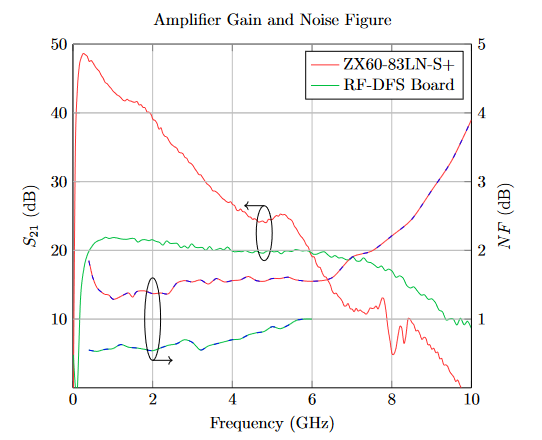
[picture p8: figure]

Figure 5: Power sweep of the ADL5902-EVALZ. R6 = 1180Ω and R2 = 2000Ω.

The poor performance of the RF-DFS board across frequency can likely be attributed to steep gain falloff even in the operating frequency. It’s possible the sub-2 GHz TSS would shown much better performance than the ZX60 LNA, but 2 GHz was the minimum output frequency on available signal generators at the time.

These tests primarily indicate two things: that a combination of low noise and high gain can increase receiver sensitivity, and give a baseline for systems utilizing the ADL5902. More in-depth testing could potentially determine how strongly gain or noise figure affect TSS independently, but a greater selection of LNAs is necessary.

Template #: 000.05.05.00.00-0003-TPT Version: A Page 5 of 5

Title: Tangential Sensitivity of ADL5902-Based Receivers Owner: [Nguyen] Date: 2023-08-15 NRAO Doc. #: [002.35.25.05.20-003] Version: 1

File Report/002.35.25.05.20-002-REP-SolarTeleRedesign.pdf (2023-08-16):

Title: Redesign of the Visitor Center Solar Telescope | Owner: R. Nguyen | Date: Aug 16, 2023
NRAO Doc #: 002.35.25.05.20-002-REP | | Version: A

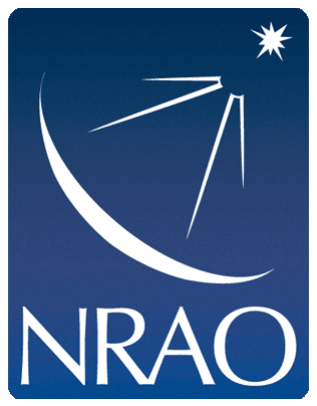
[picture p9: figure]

# Redesign of the Visitor Center Solar Telescope

### 002.35.25.05.20-002-REP

## Status: RELEASED

Prepared By | Organization | Date
Remy Nguyen Engineering Intern | NRAO Electronics Div. | 8/16/2023
Approvals | Organization | Signatures
Tyler Mobraten Electronics Engineer II | NRAO Electronics Division
Steve Wimbrow Electronics Engineer IV | NRAO Electronics Division
Dave Schafer Division Head | NRAO Electronics Division
Released By | Organization | Signature
Dave Schafer Division Head | NRAO Electronics Division

Page 1 of 10

## Change Record

Version | Date | Author | Affected Section(s) | Reason
01 | Aug 15, 2023 | R. Nguyen | All | Initial Draft
02 | Aug 16, 2023 | T. Anderson R. Nguyen | All | Edits
A | Aug 16, 2023 | T. Anderson | All | Review

## Contents

1 Introduction | 4
1.1 Purpose | | 4
1.2 Scope | | 4
1.3 Verb Convention | | 4
2 Related Documents and Drawings | 4
2.1 Applicable Documents | | 4
2.2 Reference Documents | | 4
3 System Overview | 5
3.1 Requirements | | 5
3.2 Architecture | | 5
3.3 Power Distribution | | 6
4 Tuning System Gain | 7
4.1 Installation Notes | | 8
5 Calculating Receiver Input Power | 8
5.1 Antenna Power Measurements | | 9
5.2 Final Thoughts | | 10

## List of Figures

1 | RF Signal Block Diagram | | 5
2 | 49 dB RF Gain Block | | 6
3 | DC Power Distribution Block Diagram (Maximum Ratings) | | 6
4 | Output Voltage of the ADL5902-EVALZ as a Function of Input Power | | 7
5 | Optional Output Scaling Circuit | | 7
6 | Signal Trace With 41 dB of Gain From Two ZX60-06203ALN+ LNAs | | 10

## 1 Introduction

### 1.1 Purpose

Located behind the Visitor Center at the Very Large Array (VLA) is a radio telescope that converts RF solar energy into a DC voltage through amplification. It was originally constructed in 2013 and is no longer functioning as of June 2023. Weathered components and lack of sufficient documentation to repair the telescope to its original state has warranted a redesign of the entire system to be more appealing to visitors and resistant to wear.

### 1.2 Scope

This document will describe the design choices made in development of the new solar telescope. Calculations and experiments to support design decisions will be demonstrated along with constraints and requirements.

### 1.3 Verb Convention

“Must” for an obligation; “must not” for a prohibition.

“May” for a discretionary action; “should” for a recommendation.

“Will” is used to indicate a future happening/action.

## 2 Related Documents and Drawings

### 2.1 Applicable Documents

The following documents may not be directly referenced herein, but may provide necessary context or supporting material.

Ref. No. | Document Title | Rev/Doc. No.
AD01 | Desiderata for Solar Observing with the EVLA | EVLAM_70
AD02 | EVLA Hardware Modifications in Support of Solar Ob-serving | EVLAM_72

### 2.2 Reference Documents

The following documents are referenced within this text:

Ref. No. | Document Title | Rev/Doc. No.
RD01 | Solar Brightness Temperature and Corresponding An-tenna Noise Temperature at Microwave Frequencies | Online (https://ipnpr.jpl.nasa.gov/progress_report/42-175/175E.pdf)
RD02 | Antenna Engineering Handbook | DSOC Bookcase
RD03 | Tools of Radio Astronomy | Privately Owned
RD04 | X-Band System Performance of the Very Large Array | Online (https://tmo.jpl.nasa.gov/progress_report/42-92/92O.PDF)
RD05 | 10-60 GHz G/T Measurements Using the Sun as a Source–A Preliminary Study | Online (https://www.govinfo.gov/content/pkg/GOVPUB-C13-53a55ea34f3ca8aaacf289a9caa0bee6/pdf/GOVPUB-C13-53a55ea34f3ca8aaacf289a9caa0bee6.pdf)

## 3 System Overview

The heart of the telescope is an conical corrugated X-band horn antenna originally used to receive Voyager transmissions at 8.4 GHz; this is to be unchanged in the redesign. Power is supplied through a 15 volt linear DC power supply located inside the visitor center in order to eliminate radio frequency interference (RFI) caused by AC power and switching power supplies.

As the telescope is pointed towards the various objects, RF energy is received by the antenna and amplified. A rectifying circuit converts the RF power into a DC voltage and further amplifies it before outputting to a voltmeter. The DC gain should be adjusted so that as the telescope is pointed directly at the sun, the voltmeter should raise noticeably from its value when pointed at a cold sky¹
. When pointed at the ground or an object, the reading will increase to a maximum due reflections and filling of the antenna sidelobes. This is further explained in Section 5.1.

### 3.1 Requirements

Being a visitor center attraction, the device should be engaging and appealing to visitors. In order to achieve this, a transparent enclosure will show the electronics and the voltmeter driven by solar energy will provide user feedback. The enclosure of the previous design was made of some sort of polycarbonate material which suffered from yellowing in the sun. Additionally, small computer fans with a mesh screen mounted directly to the enclosure were used to decrease operating temperature but allowed dust to accumulate over the years. In essence, the new design goals are as follows:

(1) Utilizes a transparent enclosure or panel to view electronics, ideally one which will not yellow or fade easily.
(2) Must be dustproof and resilient to accumulation of debris inside the enclosure while still venting heat from electronics.
(3) Electronics must be powered by a fixed DC linear power supply and easily serviceable.
(4) There must be a measurable voltage delta when pointing the telescope at various RF sources.

The first two requirements were fulfilled by Tristen James in designing the enclosure. The following requirements will be discussed in this report.

### 3.2 Architecture

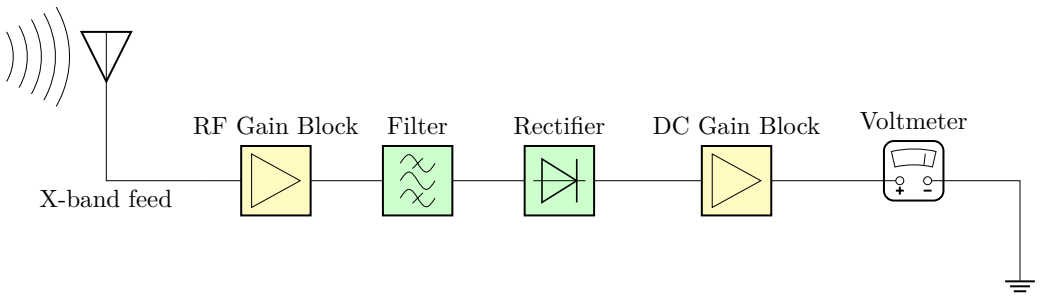
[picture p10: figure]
X-band feed; RF Gain Block Filter; Rectifier; DC Gain Block; Voltmeter

Figure 1: RF Signal Block Diagram.

1Cold sky is defined when there are no notable RF emitting objects in the beamwidth. Experimentally, these readings seem to be equivalent to the receiver noise floor.

Many of the RF components were either reused from the previous design or gathered at no cost. The RF gain block shown in Fig. 1 and 2 utilizes 3 low noise amplifiers (LNAs) and an attenuator. The first 2 LNAs are Mini-Circuits ZX60-06203ALN+ which provide a combined gain of 41 dB; they are followed by a ZX60-83LN-S+ which provides a mean gain of 15 dB in the filter bandwidth. These amplifiers are followed by an attenuator whose purpose will be described in Section 4. It is important to note that the receiver noise figure is about 2 dB – a higher noise figure could result in an undetectable sun/sky delta.

20.5 dB | 20.5 dB | 15 dB | -7 dB

Figure 2: 49 dB RF Gain Block.

The bandpass filter does not have an attached datasheet but it resembles an equiripple filter and measured a 3 dB passband of about 7.8–8.9 GHz.

The rectifier and DC gain block are integrated into a PCB with SMA connectors. The former utilizes an Analog Devices ADL5902, providing a linear-in-decibel output that can be scaled by the choice of resistors on the board or the following gain element. The DC gain block utilizes an LM358 op amp with adjustable gain via potentiometer.

### 3.3 Power Distribution

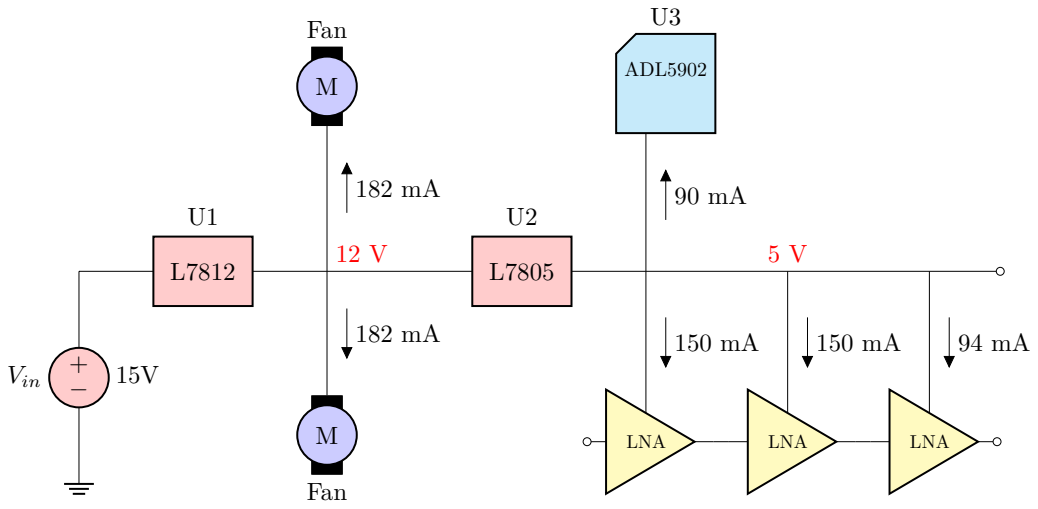
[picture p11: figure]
+ Vin; LNA; ADL5902; Fan

Figure 3: DC Power Distribution Block Diagram (Maximum Ratings).

As part of the effort to make the telescope more modern and visually appealing, the protoboard on the previous design was replaced with a PCB that contains the voltage regulators, the RF power detector IC, and dual noninverting op amps. The 15 volt supply is dropped to 12 volts and 5 volts via linear regulators, each of which powers different components. Figure 3 shows the maximum current draw of each component to ensure that the system does not exceed the 1.5 amp rating of the L78XX chips.

## 4 Tuning System Gain

Figure 4 shows the voltage-power curve of the ADL5902-EVALZ²
at the telescope’s operating frequency. Pointing the telescope at a high temperature object will produce an input power higher than pointing it at the cold sky; this dynamic range is represented by the dotted lines and filled section of the curve³
. Adding
attenuation or RF gain will shift this area to the left or right respectively. Adding DC gain will increase the slope of this curve and vice versa. Ideally, the RF gain should be adjusted such that the low end is roughly

### Vout (V)

Vout vs. Pin at 8.4 GHz

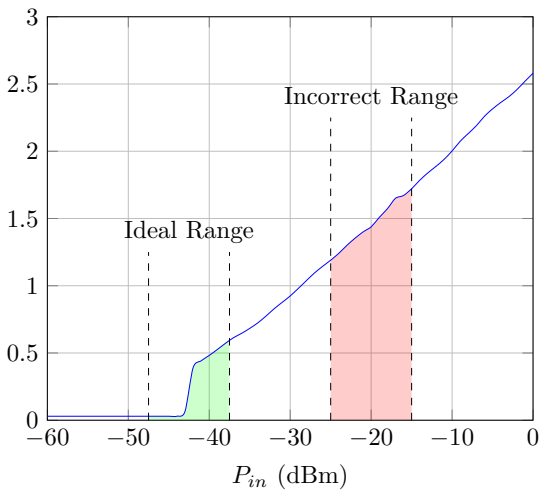
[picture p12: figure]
Ideal Range; Incorrect Range; Pin (dBm)

Figure 4: Output Voltage of the ADL5902-EVALZ as a Function of Input Power.

0 volts whereas the the high end is scaled to 3 volts by the DC gain block. In this case, amplification from the DC gain block will have negligible effect on the low end. If, for some reason, granular attenuation is not possible, the DC gain will cause the nonzero low end to increase above 0 volts. A simple solution is presented in Fig. 5 where the negative terminal of the voltmeter can be set to reference a nonzero voltage. In reality, the sensitivity of the receiver will prevent a perfect 0 to 3 volt scaling at all times. Thus, in order

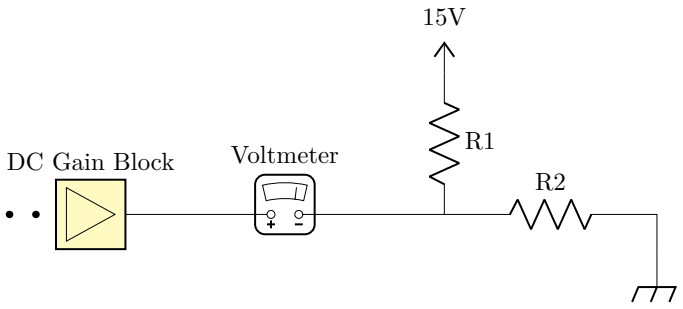
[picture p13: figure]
Voltmeter; DC Gain Block

Figure 5: Optional Output Scaling Circuit.

2Resistor values were changed on the evaluation board to achieve 86.3 mV/dB slope: R6 = 1180Ω and R2 = 2000Ω 3The range has been enlarged for the purpose of demonstration. The true range is much smaller (Section 5.1)

to ensure some amount of voltmeter deflection occurs despite environmental changes, a practical range around 0.5–2.5 volts may be desired.

### 4.1 Installation Notes

Figure 2 shows 49 dB of RF gain; this was determined to be functional with the antenna and log-detector via testing, however, ±1 dB of attenuation may work if the DC gain block is scaled correctly. Exact numbers are not shown for DC gain because slight variations in cable loss and component accuracy make it difficult to calculate. The easiest way to determine DC gain is simply to measure the voltage readings at the receiver output and adjust accordingly.

## 5 Calculating Receiver Input Power

The first step to determine RF gain will be to find the power delta as the antenna is pointed at the sun from a cold sky; note that this may vary daily and annually depending on solar cycle[RD01, Fig. 2]. This calculation also assumes that solar flux density is constant across the entire frequency range of the receiver. This is a limitation of available information on solar flux density; in practice, it generally increases with frequency[RD05]. Instantaneous channel power received by the antenna from a celestial source in watts, in an additive white Gaussian noise (AWGN) channel, PR, is defined by Eq. 1[RD02, eq. (41-2)]

PR = Psun + Pnoise | (1)
PR = SAe∆f + kBT ∆f

where: S is the source flux density in W m−2 Hz−1 ,
Ae is the effective aperture area in m²

∆f is the receiver bandwidth in Hz,
kB is the Boltzmann constant in J K−1 , and
T is the system noise temperature in K.

To simplify calculations, we will focus on power spectral density (PSD) defined as P(f) in W/Hz, ignoring the receiver bandwidth for now. Additionally, it is safe to assume that PR = Pnoise when the antenna is pointed at a cold sky.

PR(f) = Psun(f) + Pnoise(f) | (2)
= SAe + kBT

Effective aperture at a fixed wavelength λ can be calculated using measurements of the antenna as shown in Eq. 3[RD02, pg. (15-27)][RD03, eq. (5.58)]

Ae =

λ

2
4π
G | (3)

=

πd²
4

ηa

where: G is linear antenna gain,
d is the diameter of the circular horn at the aperture, and ηa is the unitless aperture efficiency.

An ideal horn antenna has an ηa of 0.522. The calculations for this design will use an approximate value of 0.5⁴
. The antenna diameter at the opening measures 34 cm, resulting in an effective area of 0.0454 m² or -13.4 dB m²

Values for solar flux density S must be found within the operating frequency. Ho et al.[RD01] measured mean, minimum, and maximum values for solar flux density at 2800 MHz and 8800 MHz but only numbers for the former are shown in the text. However, they claim that solar flux density at 8800 MHz are higher by a factor of 2.17 on average, thus, the mean, minimum, and maximum values at 2800 MHz can be multiplied by 2.17 to achieve approximate values for S. Additionally, solar brightness temperature shown in [RD01, Fig. 5] can be used to calculate solar flux density via [RD01, eq. (2)]. The former method shows higher dynamic range and is shown in Table 1 in solar flux units⁵
| Smin | Sµ | Smax
2.8 GHz | 70 SFU | 150 SFU | 280 SFU
8.8 GHz | 152 SFU | 326 SFU | 608 SFU

Table 1: Solar Flux Density S at 8.8 GHz Extrapolated by Multiplying S in [RD01] at 2.8 GHz by a Factor of 2.17.

With values for S and Ae found, we can now calculate Psun(f) with equation 2 to be -181.6 dBm/Hz at Smin. A problem arises when comparing this to the thermal noise PSD of -174 dBm/Hz at 300 K; because the power received by the sun is below the noise floor, the increase in PR due to Psun will be very small compared to Pnoise.

The nominal 7.6 dB difference between the Pnoise(f) and Psun(f) means that pointing the antenna at the sun will raise the antenna output power by a mere 0.7 dB at minimum. If a receiver noise figure of 2 dB is to be assumed, this output power delta ∆P decreases to 0.45 dB⁶

∆P =

[
| PR(f)
| Pnoise(f)

]

dB

=

[
Psun(f) + Pnoise(f)

Pnoise(f)

]

dB
= 10 log10 (
1 + 10−0.76−0.2

)

= 0.452 dB

### 5.1 Antenna Power Measurements

In order to confirm these calculations, the antenna was connected to an Anritsu MS2720T/720 spectrum analyzer and pointed at various targets.

4The x-band horn measured an estimated aperture efficiency of 0.62±0.03 but only when mounted to the VLA dish[RD04]. This design will assume the antenna to be a standard horn antenna.
5One solar flux unit (SFU) is equal to 10−22 W m−2 Hz−1
6∆ is typically used to denote a difference of linear terms. Here it is being used to denote a difference in logarithmic terms which translates to a linear ratio.

Ground
(-134.2 dBm/Hz)
Sun
(-136.3 dBm/Hz)
Cold Sky
(-136.9 dBm/Hz)

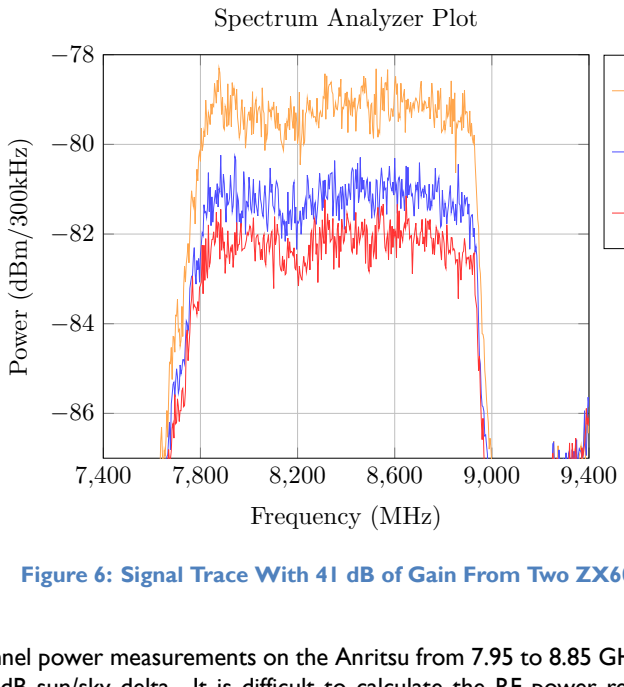
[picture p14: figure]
Frequency (MHz); Power (dBm/300kHz); Spectrum Analyzer Plot

Figure 6: Signal Trace With 41 dB of Gain From Two ZX60-06203ALN+ LNAs.

Mean channel power measurements on the Anritsu from 7.95 to 8.85 GHz show a 2.7 dB ground/sky delta and a 0.6 dB sun/sky delta. It is difficult to calculate the RF power received from the ground prior to measurement, however, the sun/sky delta is well within range of expected values.

### 5.2 Final Thoughts

These measurements and the preceding calculations were the basis for design decisions in Section 3.2. It’s possible other architectures would operate more favorably but further testing is required. Some ideas to increase sun/sky dynamic range would be to sum the two polarized feeds from the antenna via combiner or to create dual-channel rectifier and combine the outputs via summing op-amp, however, these remain as hypotheses at the time.

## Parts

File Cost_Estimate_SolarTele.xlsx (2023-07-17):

NRAO Cost Estimator
Account Number | Quantity | Unit Price | Extended Price | Description | Model Number | Vendor | Link
 | 2 | $0.47 | $0.94 | 0.33 uF Tantalum Capacitor - 0805 | TAJR334K020RNJ | DigiKey | https://www.digikey.com/en/products/detail/kyocera-avx/TAJR334K020RNJ/1470369
 | 2 | $0.79 | $1.58 | 0.1 uF Tantalum Capacitor - 0805 | TAJR104K035RNJ | DigiKey | https://www.digikey.com/en/products/detail/kyocera-avx/TAJR104K035RNJ/1470303
 | 1 | $0.10 | $0.10 | 0.1 uF Capacitor - 0805 | CL21B104KBCNNNC | DigiKey | https://www.digikey.com/en/products/detail/samsung-electro-mechanics/CL21B104KBCNNNC/3886661
 | 2 | $0.10 | $0.20 | 100 pF Capacitor - 0806 | CL21C101JCANNNC | DigiKey | https://www.digikey.com/en/products/detail/samsung-electro-mechanics/CL21C101JCANNNC/3886919
 | 1 | $1.73 | $1.73 | On Shore Technology 8 Position Terminal Block (5.08mm) | OSTTC082162 | DigiKey | https://www.digikey.com/en/products/detail/on-shore-technology-inc/OSTTC082162/614564
 | 6 | $3.99 | $23.94 | Molex SMA Jack - Edge Mount | 732511153 | DigiKey | https://www.digikey.com/en/products/detail/molex/0732511153/11305709
 | 2 | $0.10 | $0.20 | 0 Ohm Resistor - 1206 | RC1206JR-070RL | DigiKey | https://www.digikey.com/en/products/detail/yageo/RC1206JR-070RL/729184
 | 1 | $0.66 | $0.66 | 60.4 Ohm Resistor - 0805 | 2176091-3 | DigiKey | https://www.digikey.com/en/products/detail/te-connectivity-passive-product/2176091-3/4033894
 | 1 | $0.19 | $0.19 | 1.43 kOhm Resistor - 1206 | ERJ-8ENF1431V | DigiKey | https://www.digikey.com/en/products/detail/panasonic-electronic-components/ERJ-8ENF1431V/88891
 | 1 | $0.36 | $0.36 | 3.74 kOhm Resistor - 0805 | ERJ-PB6B3741V | DigiKey | https://www.digikey.com/en/products/detail/panasonic-electronic-components/ERJ-PB6B3741V/6213441
 | 1 | $0.10 | $0.10 | 2 kOhm Resistor - 0805 | RNCP0805FTD2K00 | DigiKey | https://www.digikey.com/en/products/detail/stackpole-electronics-inc/RNCP0805FTD2K00/2240237
 | 1 | $0.10 | $0.10 | 1.02 kOhm Resistor - 1206 | RC1206FR-071K02L | DigiKey | https://www.digikey.com/en/products/detail/yageo/RC1206FR-071K02L/728390
 | 2 | $2.10 | $4.20 | 5 kOhm Potentiometer - Bourns 3006P Horizontal | 3006P-1-502LF | DigiKey | https://www.digikey.com/en/products/detail/bourns-inc/3006P-1-502LF/1087582
 | 2 | $0.10 | $0.20 | 10 kOhm Resistor - 1206 | RMCF1206FT10K0 | DigiKey | https://www.digikey.com/en/products/detail/stackpole-electronics-inc/RMCF1206FT10K0/1759669
 | 1 | $0.77 | $0.77 | STMicroelectronics L7815 - TO220 | L7815ABV | DigiKey | https://www.digikey.com/en/products/detail/stmicroelectronics/L7815ABV/1038268
 | 1 | $0.77 | $0.77 | STMicroelectronics L7805 - TO220 | L7805ABV | DigiKey | https://www.digikey.com/en/products/detail/stmicroelectronics/L7805ABV/634711
 | 1 | $17.39 | $17.39 | Analog Devices RF Detector IC | ADL5902ACPZ-R7 | DigiKey | https://www.digikey.com/en/products/detail/analog-devices-inc/ADL5902ACPZ-R7/2417115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
 | 1 | $0.41 | $0.41 | Texas Instruments Op-Amp - 8DIP | LM358AP | DigiKey | https://www.digikey.com/en/products/detail/texas-instruments/LM358AP/379836
 | 1 | $9.95 | $9.95 | Large 3V Analog Panel Meter | 3989 | DigiKey | https://www.digikey.com/en/products/detail/adafruit-industries-llc/3989/9770510
 | 0 | $0.00 | $0.00
 | 0 | $0.00 | $0.00
 | 0 | $0.00 | $0.00
 | 0 | $0.00 | $0.00
 | 0 | $0.00 | $0.00
 | 0 | $0.00 | $0.00
 | 0 | $0.00 | $0.00
 | 0 | $0.00 | $0.00
 | 0 | $0.00 | $0.00
 | 0 | $0.00 | $0.00
 | 0 | $0.00 | $0.00
 | 0 | $0.00 | $0.00
 | 0 | $0.00 | $0.00
 | 0 | $0.00 | $0.00
 | 0 | $0.00 | $0.00
 | 0 | $0.00 | $0.00
 | 0 | $0.00 | $0.00
 | 0 | $0.00 | $0.00
 | 0 | $0.00 | $0.00
 |  | Total | $63.79

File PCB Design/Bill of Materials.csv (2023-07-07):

# | Reference | Qty | Value | Footprint | DNP
1 | C1, C3 | 2 | 0.33uF | Capacitor_Tantalum_SMD:CP_EIA-2012-12_Kemet-R
2 | C2, C4 | 2 | 0.1uF | Capacitor_Tantalum_SMD:CP_EIA-2012-12_Kemet-R
3 | C9 | 1 | 100 nF | Capacitor_SMD:C_0805_2012Metric
4 | C10, C12 | 2 | 100 pF | Capacitor_SMD:C_1206_3216Metric
5 | D1 | 1 | D_Zener | Diode_SMD:D_1206_3216Metric | DNP
6 | J1 | 1 | Screw_Terminal_01x08 | TerminalBlock_Phoenix:TerminalBlock_Phoenix_MKDS-3-8-5.08_1x08_P5.08mm_Horizontal
7 | J2 | 1 | Conn_01x01 | Connector_PinHeader_1.00mm:PinHeader_1x01_P1.00mm_Vertical | DNP
8 | J3, J4, J5, J6, J7, J8 | 6 | SMA | Connector_Coaxial:SMA_Molex_73251-1153_EdgeMount_Horizontal
9 | R1, R6 | 2 | 0 | Resistor_SMD:R_1206_3216Metric
10 | R2, R15 | 2 | Inf | Resistor_SMD:R_1206_3216Metric | DNP
11 | R3 | 1 | 60.3 | Resistor_SMD:R_0805_2012Metric
12 | R9 | 1 | 1430 | Resistor_SMD:R_1206_3216Metric
13 | R10 | 1 | 3.74k | Resistor_SMD:R_0805_2012Metric
14 | R11 | 1 | 2k | Resistor_SMD:R_0805_2012Metric
15 | R12 | 1 | 1007 | Resistor_SMD:R_1206_3216Metric
16 | R_pot1, R_pot2 | 2 | 10k | Potentiometer_THT:Potentiometer_Bourns_3006P_Horizontal
17 | Rf1, Rf2 | 2 | 10k | Resistor_SMD:R_1206_3216Metric
18 | U1 | 1 | L7815 | Package_TO_SOT_THT:TO-220-3_Horizontal_TabDown
19 | U2 | 1 | L7805 | Package_TO_SOT_THT:TO-220-3_Horizontal_TabDown
20 | U3 | 1 | ADL5902ACPZ-R7 | imports:CP_16_20_ADI
21 | U4 | 1 | LM358 | Package_DIP:DIP-8_W7.62mm

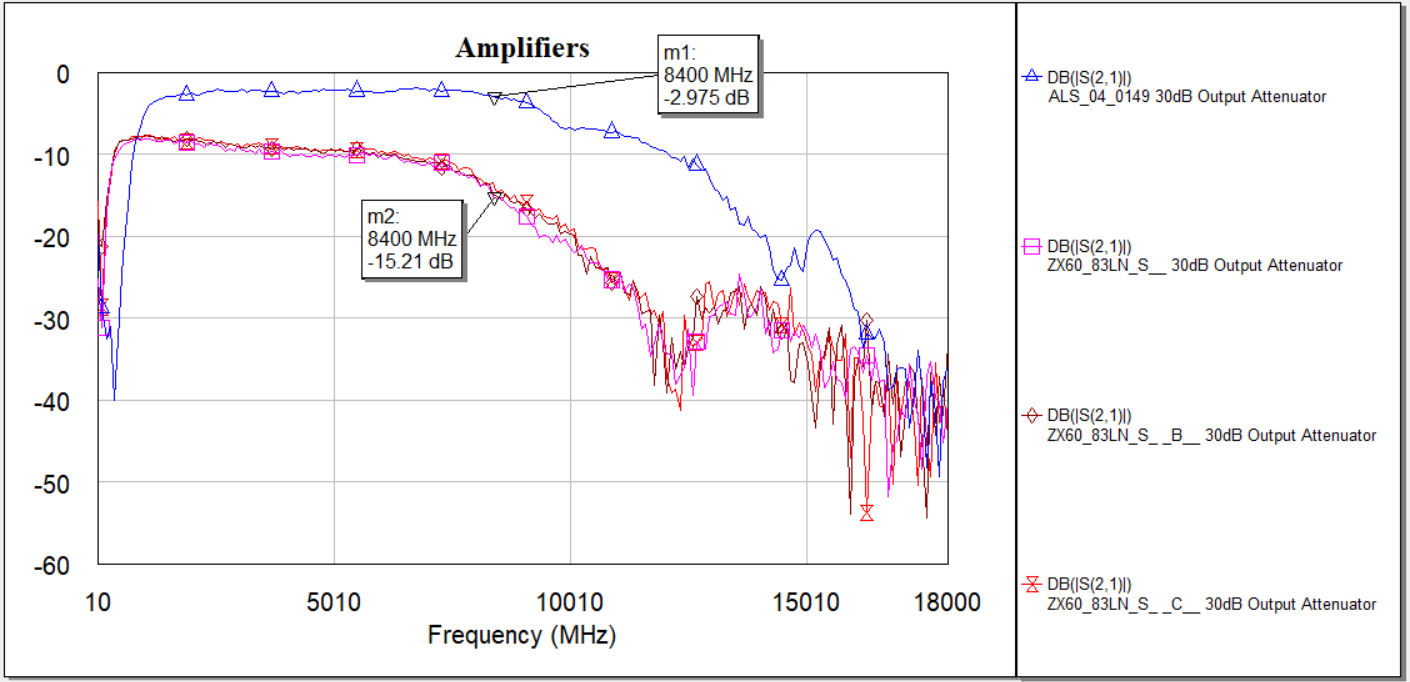
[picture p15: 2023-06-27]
MATLAB and Datalogging/Components/Amp_and_Filter_Sparam.png

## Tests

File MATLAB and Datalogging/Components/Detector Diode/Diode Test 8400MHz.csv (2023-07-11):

Pin (dBm) | Vout (mV)
-50 | -0.53
-45 | -0.55
-40 | -0.62
-35 | -0.83
-30 | -1.51
-25 | -3.74
-20 | -9.97
-17.5 | -16.44
-15 | -26.2
-12.5 | -40.28
-10 | -60.16
-7.5 | -87.2
-5 | -122.8
-2.5 | -171.9
0 | -241.9
2.5 | -329
5 | -489.8
7.5 | -635.6
10 | -918
13 | -1198
15 | -1445
17 | -1604
20 | -1716
22 | -1816
25 | -1844
27 | -1787
30 | -1748

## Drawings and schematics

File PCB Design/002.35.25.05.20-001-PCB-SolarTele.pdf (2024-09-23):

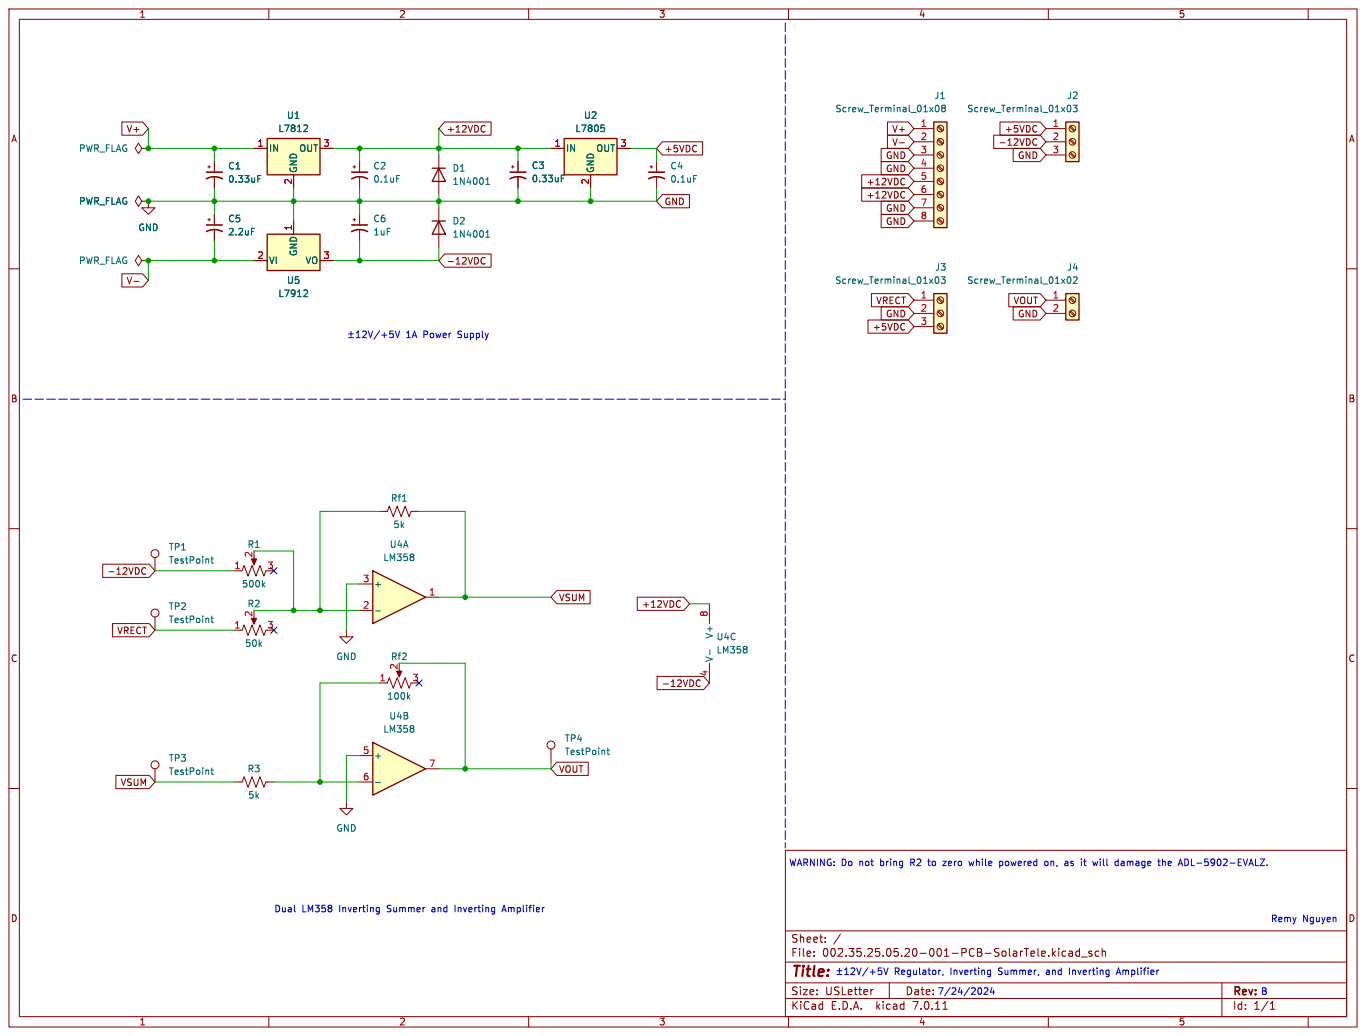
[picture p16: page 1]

Id: 1/1 Title: File: 002.35.25.05.20-001-PCB-SolarTele.kicad_sch Sheet: /

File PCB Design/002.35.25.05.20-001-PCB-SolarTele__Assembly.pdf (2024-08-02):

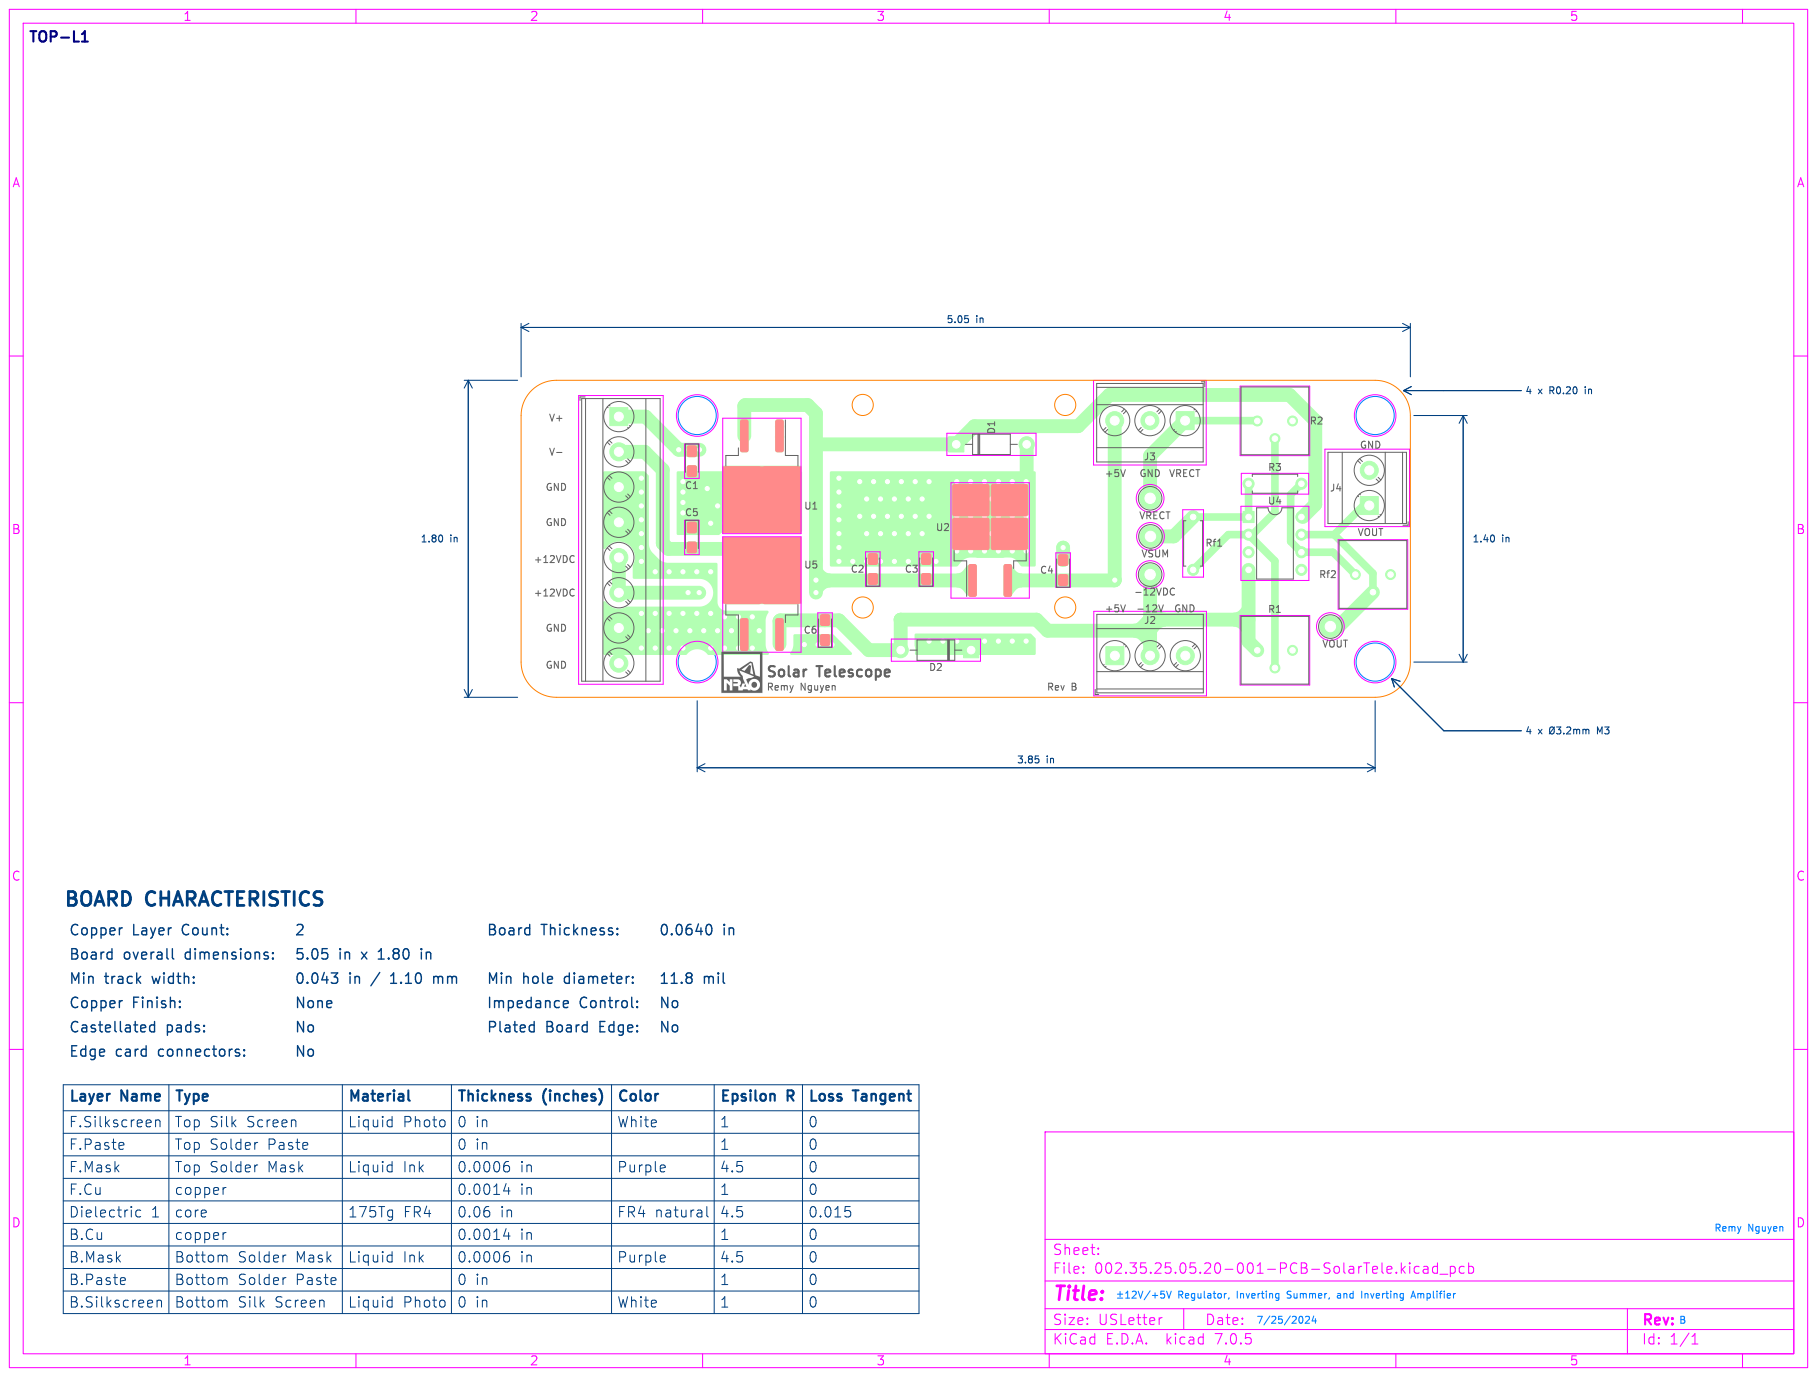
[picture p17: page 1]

Remy Nguyen Solar Telescope

Layer Name Bottom Silk Screen

1Epsilon R White Purple FR4 natural Purple White

Id: 1/1 Title: File: 002.35.25.05.20-001-PCB-SolarTele.kicad_pcb Sheet:

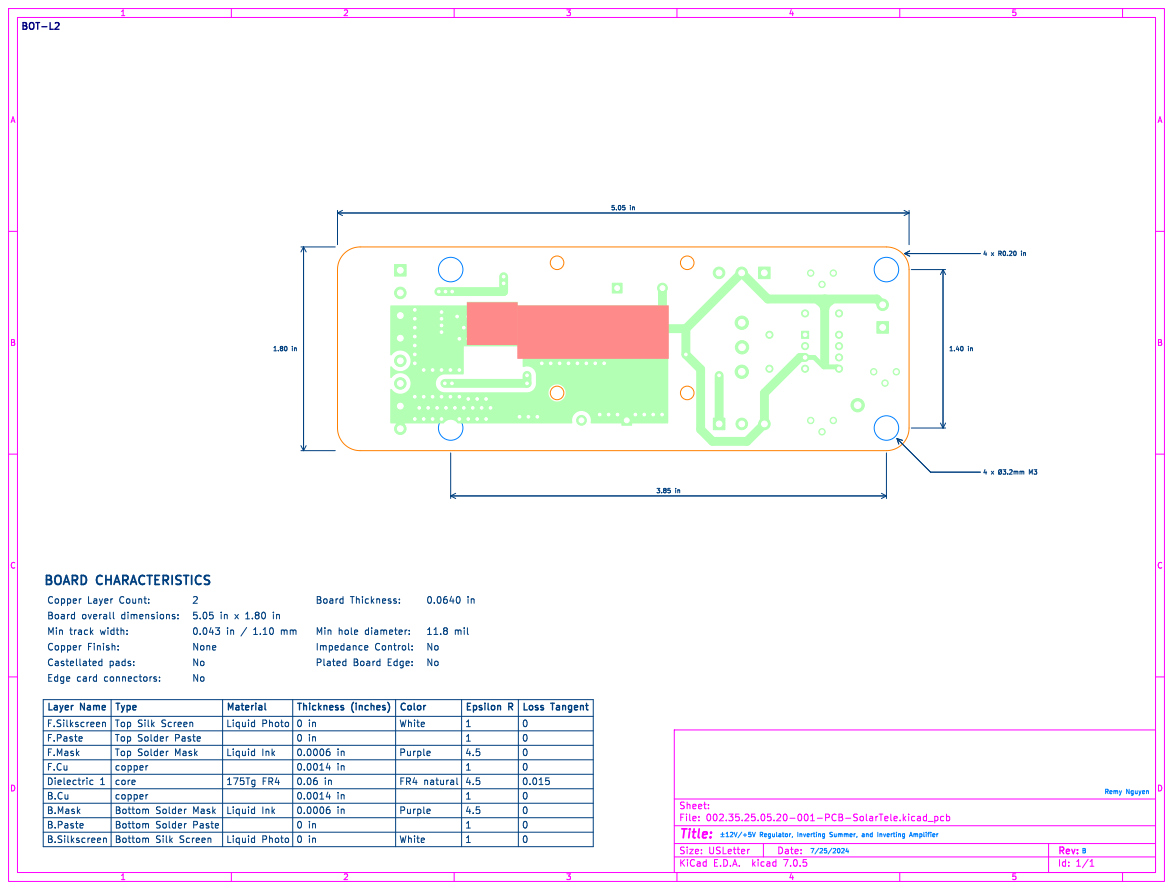
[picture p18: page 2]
Remy Nguyen B; Regulator,; Inverting; Summer, and Inverting; Amplifier 7/25/2024; D Date: KiCad; kicad; 7.0.5 Size: USLetter; Rev:; 5.05 in 11.8 mil Plated; Board; Edge:; Impedance; Control: Min hole diameter: Board; Thickness: No None; 1.80 in Castellated; pads:; Edge card; connectors: Copper; Finish:; 2 Min track; width:; No Board; overall dimensions: BOARD CHARACTERISTICS; Copper; Layer Count:; Loss; Tangent 1; 1Epsilon; R White Purple FR4 natural Purple White; 0 in Thickness; (inches)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

Layer Name Bottom Silk Screen

Id: 1/1 Title: File: 002.35.25.05.20-001-PCB-SolarTele.kicad_pcb Sheet:

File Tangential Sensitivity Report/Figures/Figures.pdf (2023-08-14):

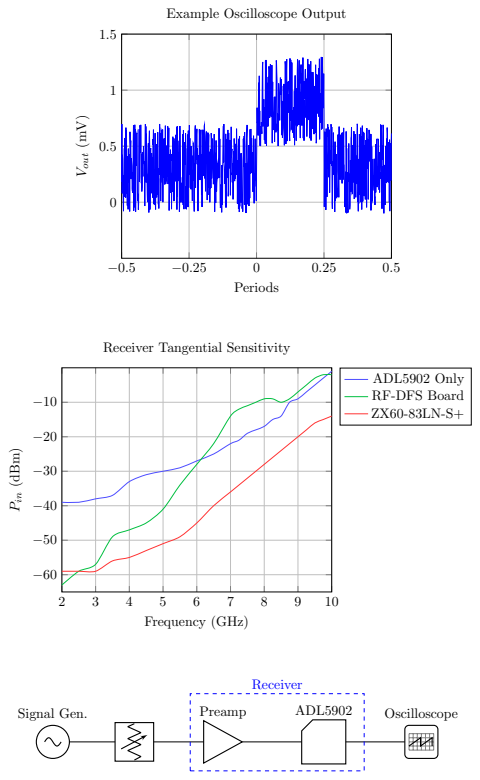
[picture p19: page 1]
Periods; Vout (mV); Frequency (GHz); Pin (dBm); ADL5902 Only RF-DFS Board ZX60-83LN-S+; Signal Gen.; Preamp; ADL5902; Oscilloscope; Receiver

Example Oscilloscope Output

Receiver Tangential Sensitivity

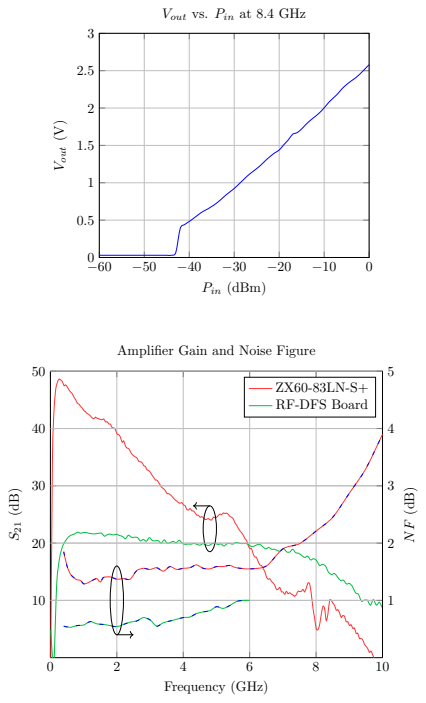
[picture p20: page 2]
Pin (dBm); Vout (V); Frequency (GHz)

Vout vs. Pin at 8.4 GHz

Amplifier Gain and Noise Figure

RF-DFS Board

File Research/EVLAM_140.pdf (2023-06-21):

Design, Prototyping and Measurement of EVLA Ku-Band Feed Horn Sivasankaran Srikanth
NRAO
November 4, 2009
Abstract:
A prototype of the Ku-band (12-18 GHz) feed horn for the EVLA has been designed, built and tested. This feed horn is a corrugated horn with a linear taper of 10.38˚; has an aperture diameter of 15.6 λ and a length of 42.3 λ at the center frequency. The horn has five machined aluminum sections including the circular input waveguide section. The feed horn has an average illumination taper of -14.0 dB at the edge of subreflector in the 12-18 GHz range. Cross-polarization is less than -27 dB in the design band. Measured return loss is better than 30 dB.
Introduction:
For a receiver temperature of 21 K, a feed illumination taper of -13 to -14 dB at the edge of the subreflector (9.3º half-angle) resulted in maximum gain/system temperature (G/T) at 15 GHz for the EVLA antenna. In order to obtain a -13.5 dB taper with a 1.5:1 bandwidth ratio, a linear taper horn would require an aperture of diameter of 12.3”. This feed horn would easily fit in the assigned area. A linear taper horn with ring-loaded corrugations in the mode converter was chosen for the Ku-band. This memo covers the design of the feed horn; prototype construction and details of measurements done at the Outside Antenna Test Range (OATR) in Socorro and at the Outside Antenna Range (OAR) in Green Bank. Far-field range measurements on two horns and comparisons with theory are shown. Results of return loss measurements are also shown.
Design and Prototyping:

The semi flare angle θ0 of prime-focus feed horns are usually large (>30˚) while for secondary focus

systems the feed horns have narrow flare angles. The spherical phase error ∆ at the aperture of a narrow flare angle horn is given by

Here r1/λ is the aperture radius in wavelengths. The beamwidth of horns with ∆<0.4 depends on the aperture size r1/λ and hence is frequency dependent. Such horns are termed “narrow band” horns. For

∆>0.5 the beamwidth is mainly determined by θ0, the phase center of the horn is near the throat and

remains almost fixed with respect to frequency. These horns are termed “wide-band” horns. For the Ku-band horn, a value of 0.58 is chosen for ∆ at the lowest frequency of operation. Acombination of

θ0= and aperture diameter of 12.3” gives the specified feed taper of -13.5 dB at the edge of the
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

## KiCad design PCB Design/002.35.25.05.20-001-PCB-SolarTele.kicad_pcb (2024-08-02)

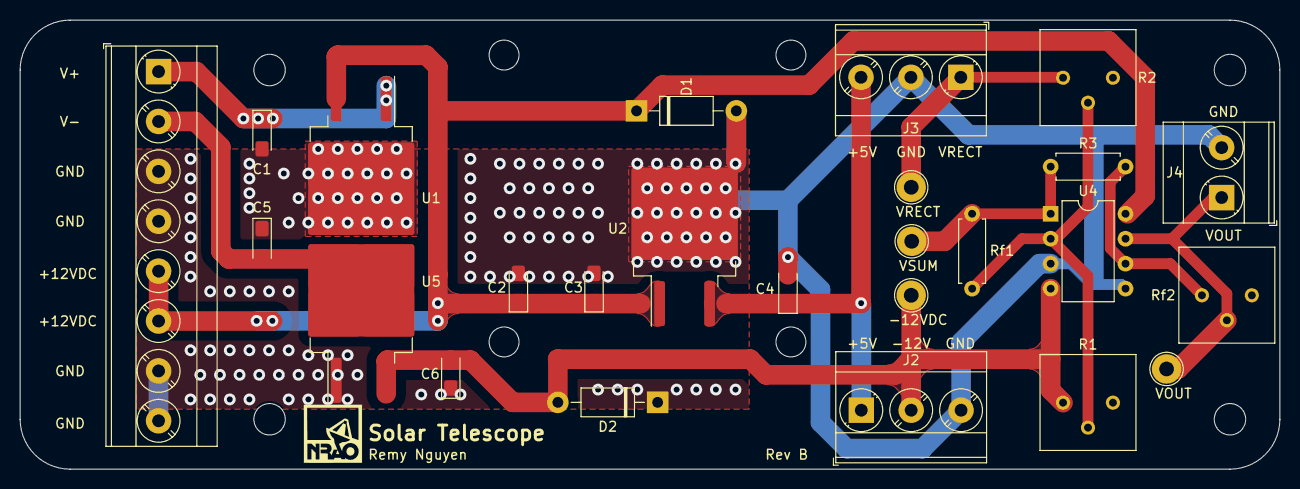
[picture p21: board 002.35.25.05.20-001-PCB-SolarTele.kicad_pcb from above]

Board: 2 copper layers, 128.3 x 45.7 mm, 26 parts (0 on the bottom side), 11 nets.

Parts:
-12VDC: TestPoint; TestPoint_Loop_D2.54mm_Drill1.5mm_Beaded
C1, C3: 0.33uF; CP_EIA-3216-10_Kemet-I_Pad1.58x1.35mm_HandSolder
C2, C4: 0.1uF; CP_EIA-3216-10_Kemet-I_Pad1.58x1.35mm_HandSolder
C5: 2.2uF; CP_EIA-3216-10_Kemet-I_Pad1.58x1.35mm_HandSolder
C6: 1uF; CP_EIA-3216-10_Kemet-I_Pad1.58x1.35mm_HandSolder
D1, D2: 1N4001; D_DO-41_SOD81_P10.16mm_Horizontal
J1: Screw_Terminal_01x08; TerminalBlock_Phoenix_MKDS-3-8-5.08_1x08_P5.08mm_Horizontal
J2, J3: Screw_Terminal_01x03; TerminalBlock_Phoenix_MKDS-3-3-5.08_1x03_P5.08mm_Horizontal
J4: Screw_Terminal_01x02; TerminalBlock_Phoenix_MKDS-3-2-5.08_1x02_P5.08mm_Horizontal
R1: 50k; Potentiometer_Bourns_3386P_Vertical
R2: 1k; Potentiometer_Bourns_3386P_Vertical
R3: 510; R_Axial_DIN0207_L6.3mm_D2.5mm_P7.62mm_Horizontal
REF: MountingHole_3.2mm_M3_ISO14580
Rf1: 510; R_Axial_DIN0207_L6.3mm_D2.5mm_P7.62mm_Horizontal
Rf2: 10k; Potentiometer_Bourns_3386P_Vertical
U1: L7812; TO-263-2
U2: L7805; TO-263-2
U4: LM358; DIP-8_W7.62mm
U5: L7912; TO-263-2
VOUT: TestPoint; TestPoint_Loop_D2.54mm_Drill1.5mm_Beaded
VRECT: TestPoint; TestPoint_Loop_D2.54mm_Drill1.5mm_Beaded
VSUM: TestPoint; TestPoint_Loop_D2.54mm_Drill1.5mm_Beaded

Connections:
+5VDC: C4.1, J2.1, J3.3, U2.3 (OUT)
+12VDC: C2.1, C3.1, D1.1 (K), J1.5, J1.6, U1.3 (OUT), U2.1 (IN), U4.8 (V+)
-12VDC: -12VDC.1, C6.2, D2.2 (A), J2.2, R1.1, U4.4 (V-), U5.3 (VO)
GND: C1.2, C2.2, C3.2, C4.2, C5.1, C6.1, D1.2 (A), D2.1 (K), J1.3, J1.4, J1.7, J1.8, J2.3, J3.2, J4.2, U1.2 (GND), U2.2 (GND), U4.3 (+), U4.5 (+), U5.1 (GND)
unnamed: R1.2, R2.2, Rf1.1, U4.2 (-)
unnamed: R3.2, Rf2.1, U4.6 (-)
V+: C1.1, J1.1, U1.1 (IN)
V-: C5.2, J1.2, U5.2 (VI)
VOUT: J4.1, Rf2.2, U4.7, VOUT.1
VRECT: J3.1, R2.1, VRECT.1
VSUM: R3.1, Rf1.2, U4.1, VSUM.1

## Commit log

2023-06-16 New Directory
    [Diode Test 8400MHz.csv]
2023-06-21 PCB completed, new report format
    [VoltageRegulator.kicad_pcb, VoltageRegulator.kicad_sch]
2023-06-23 Continued drafting report
    [VoltageRegulator.kicad_pcb]
2023-06-26 Continued work on report
    [Cost_Breakdown_SolarTele.xlsx, NRAO.RN. VR GERBER, 2 LYR.xls]
2023-06-26 Schematic Rev C
    [Cost_Breakdown_SolarTele.xlsx, VoltageRegulator.kicad_sch]
2023-06-27 Schematic Revision C - AD8317
    [VoltageRegulator.kicad_sch]
2023-06-27 Schematic Revision D Draft, Datasheets added
    [VoltageRegulator.kicad_sch]
2023-06-27 Schematic Rev C complete, ADL5902 pins reassigned; ERC pass
    [VoltageRegulator.kicad_sch]
2023-06-29 New circuit diagram with current draw
    [VoltageRegulator.kicad_sch]
2023-06-29 INLO fixed; INLO is unused differential input, not RFGND
    [VoltageRegulator.kicad_sch]
2023-06-29 Footprints assigned, LM7815 --> L7815
    [VoltageRegulator.kicad_sch]
2023-06-29 PCB Rev D drafted, DRC pass
    [S_Tele.kicad_pcb, S_Tele.kicad_sch, VoltageRegulator.kicad_pcb]
2023-06-29 LM358 I/O swapped
    [S_Tele.kicad_pcb]
2023-06-30 RF TXline width fixed, GCPW --> CPW
    [S_Tele.kicad_pcb]
2023-06-30 Added ADL5902 and fan to power diagram
2023-07-07 Bill of materials added
    [Bill of Materials.csv, Cost_Estimate_SolarTele.xlsx, S_Tele.kicad_pcb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]
2023-07-10 CPW --> GCPW for RO4350B & silkscreen added
    [S_Tele-B_Cu.gbr, S_Tele-B_Mask.gbr, S_Tele-B_Paste.gbr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]
2023-07-10 Removed kicad backups to decrease repo size
2023-07-10 10 mil RO4350B --> 30 mil, RF traces adjusted
    [S_Tele-B_Cu.gbr, S_Tele-B_Mask.gbr, S_Tele-B_Paste.gbr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]
2023-07-12 Revert "Merge conflict resolved": KiCad project corrupted
    This reverts commit 708bf57b2537bb9e720d308913f0671883acc423, reversing
    changes made to 03e59d059433c095b682b83f3c3dbb520ea51bac.
    [S_Tele.kicad_pcb]
2023-07-17 Colored figures and added rf gain block
    [Cost_Estimate_SolarTele.xlsx, NRAO.RN. VR GERBER, 2 LYR.xls]
2023-07-19 Added output scaling circuit to report
    [S_Tele.kicad_pcb, S_Tele.kicad_sch]
2023-07-20 Reverted output scaling circuit
    [Vout vs Pin.csv]
2023-07-26 Added document numbers
    [002.35.25.05.20-001-PCB-SolarTele.kicad_pcb, 002.35.25.05.20-001-PCB-SolarTele.kicad_sch]
2023-07-28 Added new tansens figure
    [TanSensADL5902.xlsx]
2023-08-01 Fixed footprint assignments in schematic
    [002.35.25.05.20-001-PCB-SolarTele.kicad_sch]
2023-08-02 Added filter s-parameters
2023-08-04 New spectrum analyzer traces added
    [Diode Test 8400MHz.csv, Vout vs Pin.csv]
2023-08-04 Component S-parameters added to report for reference (temporary)
    [Amplifiers and Filter Sparam.txt]
2023-08-11 Datalogging updated, final experiment traces added
    [Amplifiers and Filter Sparam.txt]
2023-08-11 Final trace and architecture added to report, removed indentations and hbox warnings
2023-08-11 Sch. comment: op-amp topology is incorrect
    [002.35.25.05.20-001-PCB-SolarTele.kicad_sch]
2023-08-14 TS measurements for rf-dfs board
    [TanSensADL5902.xlsx]
2023-08-14 RF-DFS measurement added to TS report
    [Amplifiers and Filter Sparam.txt, rfdfs-6g-sparam.txt]
2023-08-14 REP: Revised calculations for better flow
2024-01-22 Fixed SMA pad thickness
    [002.35.25.05.20-001-PCB-SolarTele.kicad_pcb, 002.35.25.05.20-001-PCB-SolarTele.kicad_sch]
2024-08-02 PCB updated to Revision B, see changelog for details
    [002.35.25.05.20-001-PCB-SolarTele.kicad_pcb, 002.35.25.05.20-001-PCB-SolarTele.kicad_sch]
2024-09-23 Housekeeping
    - Updated schematic with higher value resistors to prevent backcurrent.
    - Updated schematic with warning on low R2 value causing backcurrent.
    - Removed KiCad/LaTeX auxiliary files and .gitignore'd them.
    [002.35.25.05.20-001-PCB-SolarTele.kicad_sch]
